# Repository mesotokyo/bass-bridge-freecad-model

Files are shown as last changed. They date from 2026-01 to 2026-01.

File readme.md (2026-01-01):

# 5弦ベース用ブリッジ3Dモデル

5弦ベース用のブリッジを作成するための3Dモデルです。この3Dモデルは板金加工での加工を意図して制作しています。

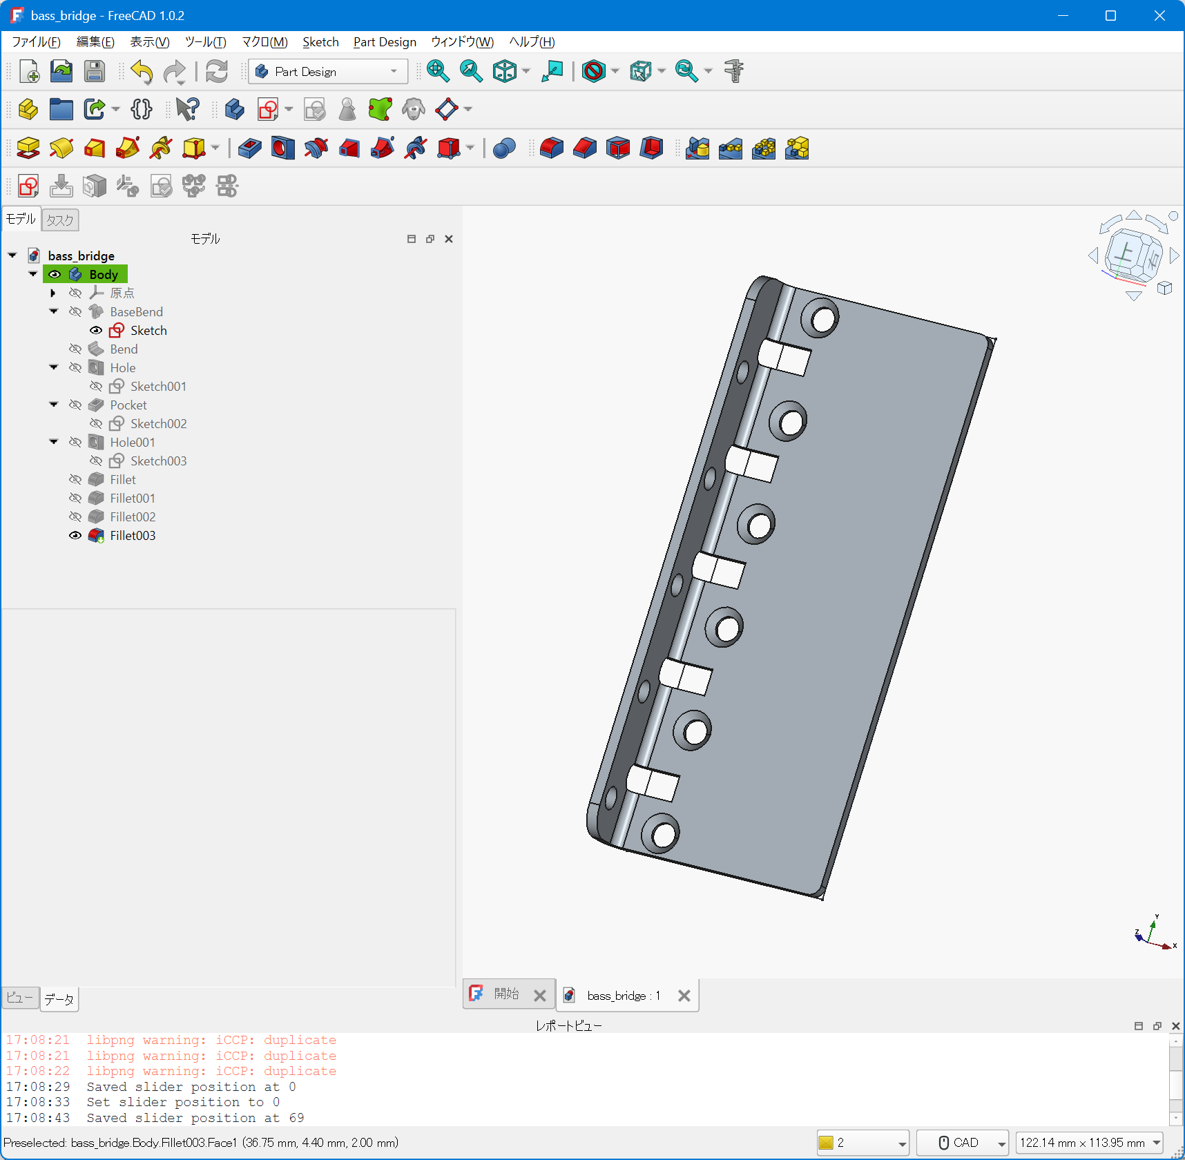
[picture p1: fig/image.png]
FreeCADで表示した全体イメージ


## 作業工程解説

FreeCADで本3Dモデルを作成する手順を[how_to_model_the_bridge](how_to_model/how_to_model_the_bridge.md)としてまとめています。ブリッジの寸法や穴の位置を変更したい場合、こちらが参考になるかもしれません。

## 寸法について

ブリッジを固定するためのネジ穴は「BADASS V」と同じ位置に配置しています。そのため、BADASS Vやその互換品（ALLPARTSの5弦ベース用「OMEGA BASS」、HIP SHOTの5STRING KICKASS BASS BRIDGEの「Mount Pattern 1」バージョン）から追加加工なしで置き換えが可能です。

ベースプレート部分の幅が41.7mm（ベース部分38mm＋曲げ部分3.7mm）、高さが100mmです。ネジ穴の間隔は18.4mmです。

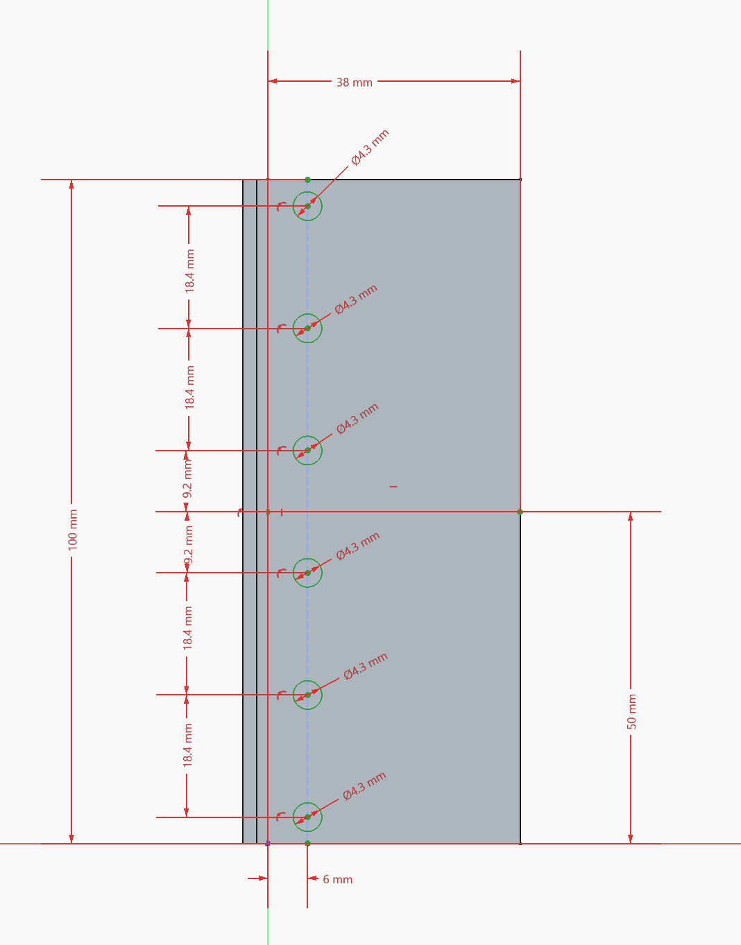
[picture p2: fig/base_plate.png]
ベースプレート部分の寸法図


弦間ピッチは19mmを想定しています。

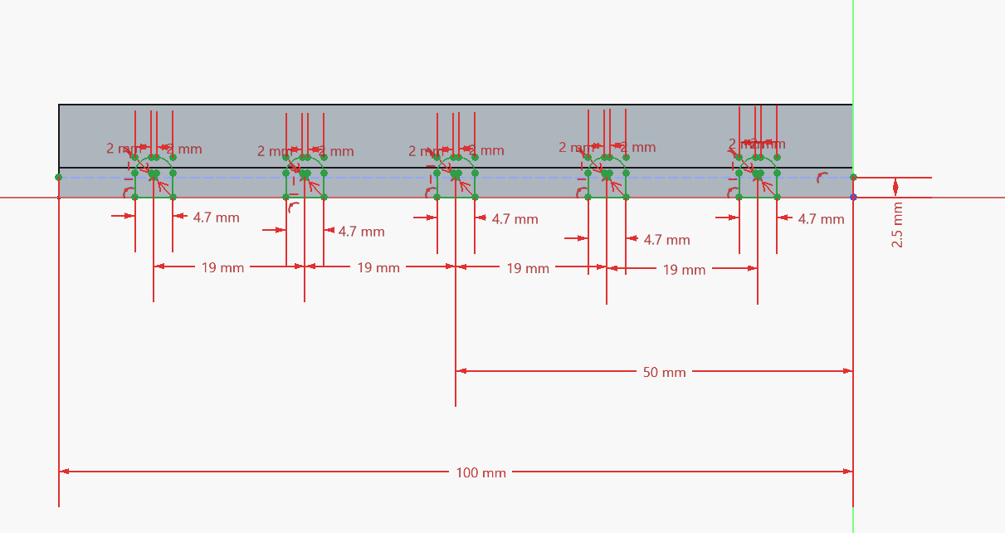
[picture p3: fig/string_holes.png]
弦を通す部分の寸法図


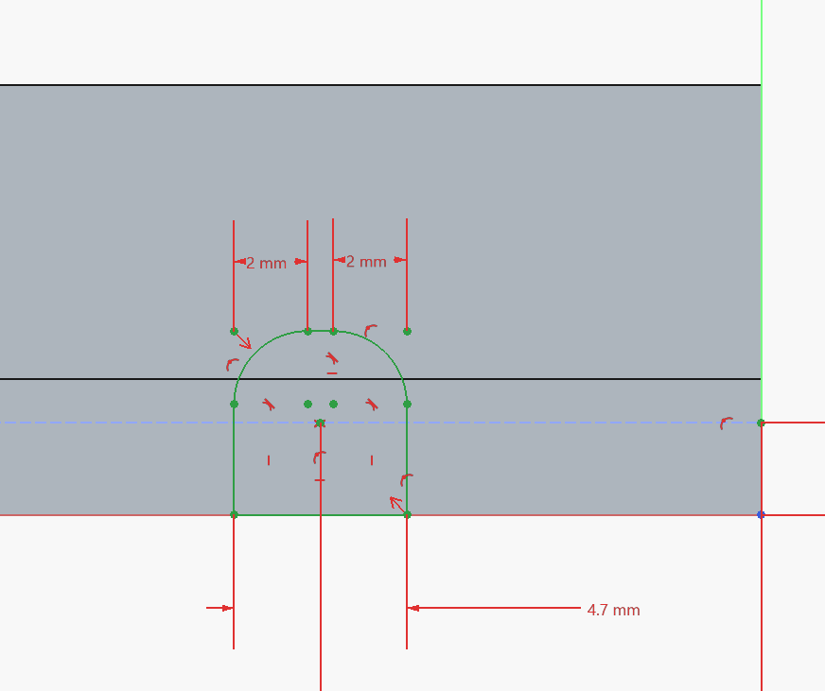
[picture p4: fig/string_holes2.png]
弦を通す穴の寸法図


サドルは19mmサイズのものを利用することを想定しています。

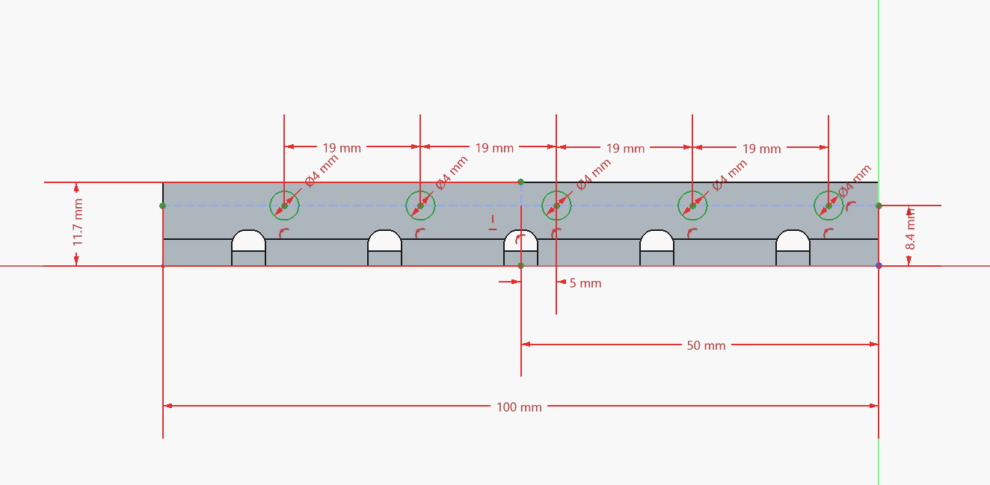
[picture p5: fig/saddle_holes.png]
サドル固定用ネジ穴の寸法図


## ライセンス

[CC-BY 4.0](https://creativecommons.org/licenses/by/4.0/deed.ja)で提供しています。

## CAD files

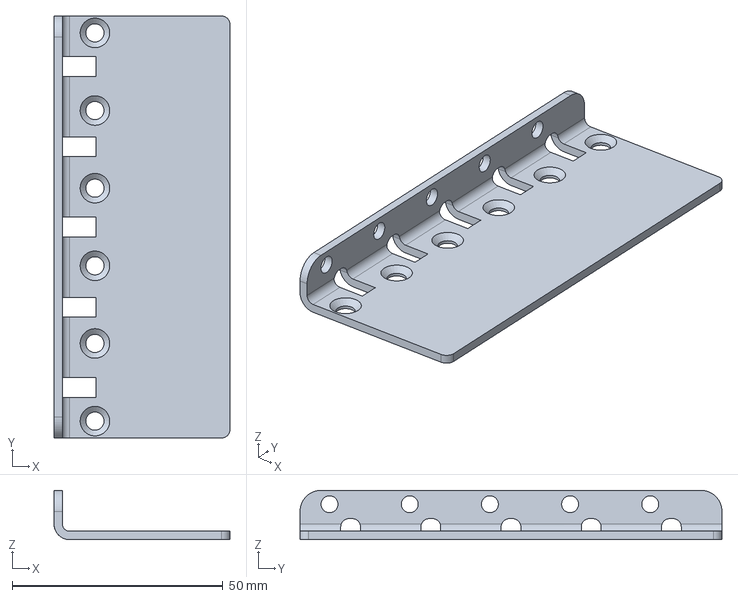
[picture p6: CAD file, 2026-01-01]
bass_bridge.FCStd
41.7 x 100.0 x 11.7 mm

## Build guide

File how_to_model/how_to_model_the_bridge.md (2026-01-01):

# FreeCADでベースブリッジを設計する

本記事では、FreeCADとSheet Metalワークベンチを使用して、板金での加工を意図した5弦ベース用ブリッジの3Dモデルを作成する方法を解説します。なお、FreeCAD自体やそのインストール方法についての解説については割愛していますので、これらについては[FreeCADのWebサイト](https://www.freecad.org/)などをご参照ください。

本記事ではFreeCAD 1.0.2のWindows版を使用しています。バージョンやOSによって画面や手順が変わる可能性がありますので、その点についてはご注意ください。

## Sheet Metalワークベンチの追加

FreeCADでは目的の操作に応じて「ワークベンチ（WorkBench）」を切り替えて作業を進めていきます。たとえば、3Dモデルに対してさまざまな操作を行うには「Part Design」ワークベンチを使います。ワークベンチの切り替えは、ツールバーのドロップダウンメニューで行えます。

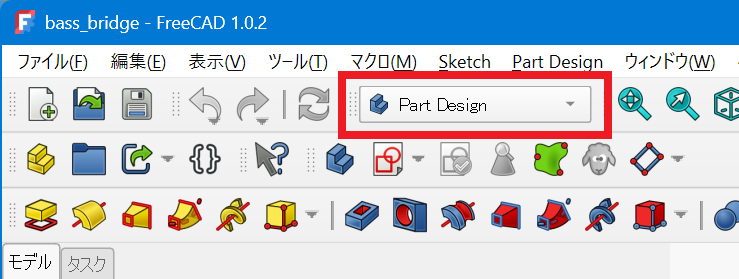
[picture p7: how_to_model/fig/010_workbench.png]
ワークベンチを選択するドロップダウンメニュー


板金加工に関連する操作は「Sheet Metal」ワークベンチで行います。このワークベンチはFreeCADには標準では含まれていないため、別途アドオン（拡張機能）の追加を行う必要があります。アドオンの追加はFreeCADを起動して「ツール」－「拡張機能の管理」メニューで行えます。

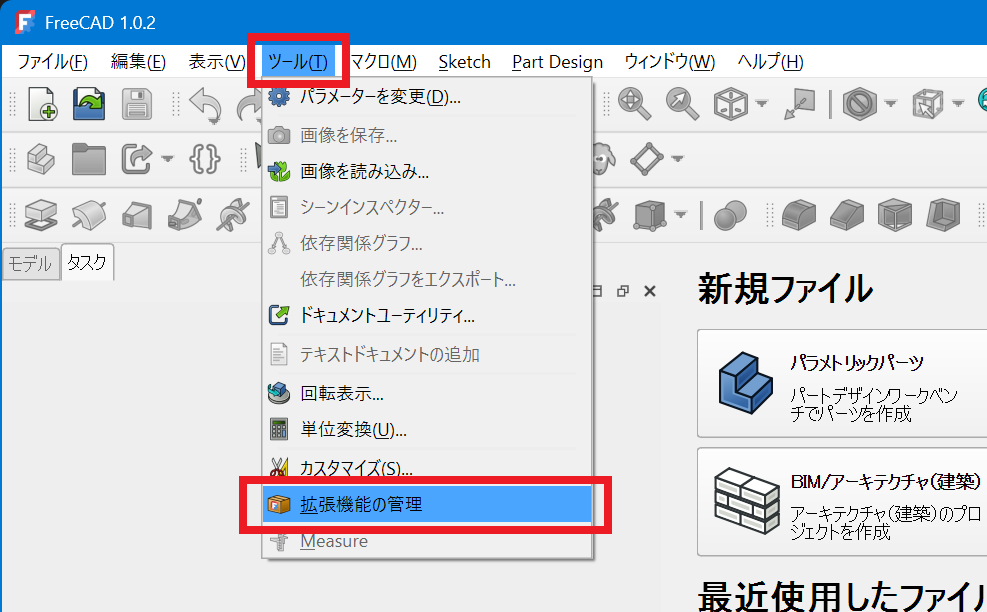
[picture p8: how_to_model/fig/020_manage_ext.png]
「拡張機能の管理」メニューでアドオンを追加できる


このメニューを選択すると、「アドオン・マネージャー」が表示されるので、ここで「SheetMetal Workbench」をクリックしてインストールを行います。画面右上に表示するアドオンを絞り込む検索ボックスがあるので、ここに「sheet」などのキーワードを入力すると探しやすいでしょう。

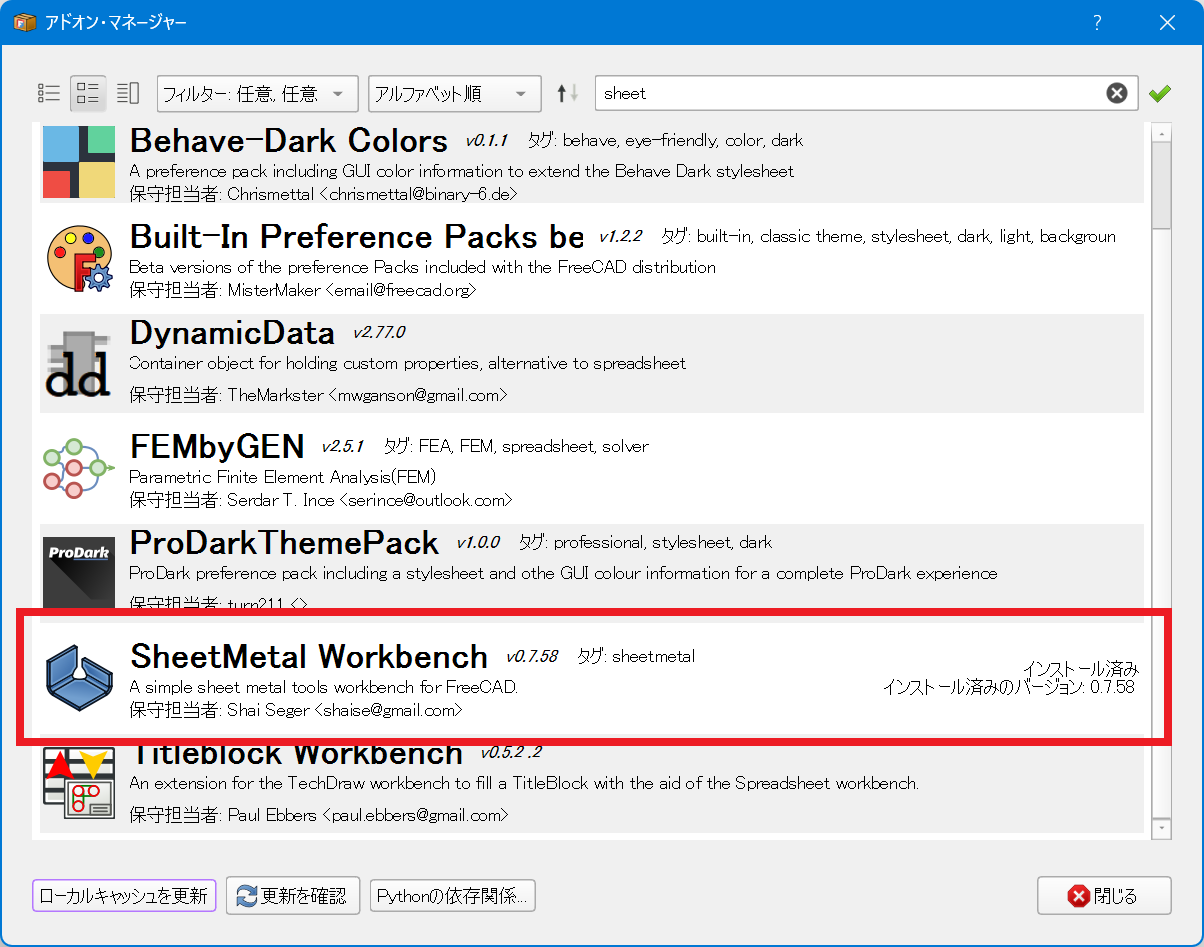
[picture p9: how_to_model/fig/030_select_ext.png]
「アドオン・マネージャー」で「SheetMetal Workbench」をインストールする


## FreeCADの操作について

FreeCADはAdobe Illustratorなどのベクターグラフィックス作成ツールに似ていますが、操作方法などはかなり異なります。たとえば、画面のスクロールはマウス中ボタン（ホイール）のドラッグで行います。始点変更は中ボタン＋右ボタン同時押し（厳密には中ボタンを押したあと、押しっぱなしにしたまま右ボタンを押す）のドラッグ操作で、表示の拡大・縮小はホイール操作で行えます。

また、図形作成などの作業中にマウスの右ボタンを押すと、その作業をキャンセルできます。Escキーでも作業をキャンセルできますが、Escキーにはタスクを閉じてワークベンチを切り替える操作も割り当てられており、Escキーを連打すると意図せずワークベンチが切り替わってしまうことがあるため、作業のキャンセルにはなるべく右クリックを使うことをおすすめします。

## ファイルの新規作成とボディーの作成

それでは、実際にモデリングを進めていきます。まず、ファイルの新規作成を行います。FreeCADを起動すると「開始」というタブが表示されるので、そこで「新規ファイル」以下にある「空ファイル」をクリックします（ツールバーの「新規」ボタンでも同じ操作が可能です）。

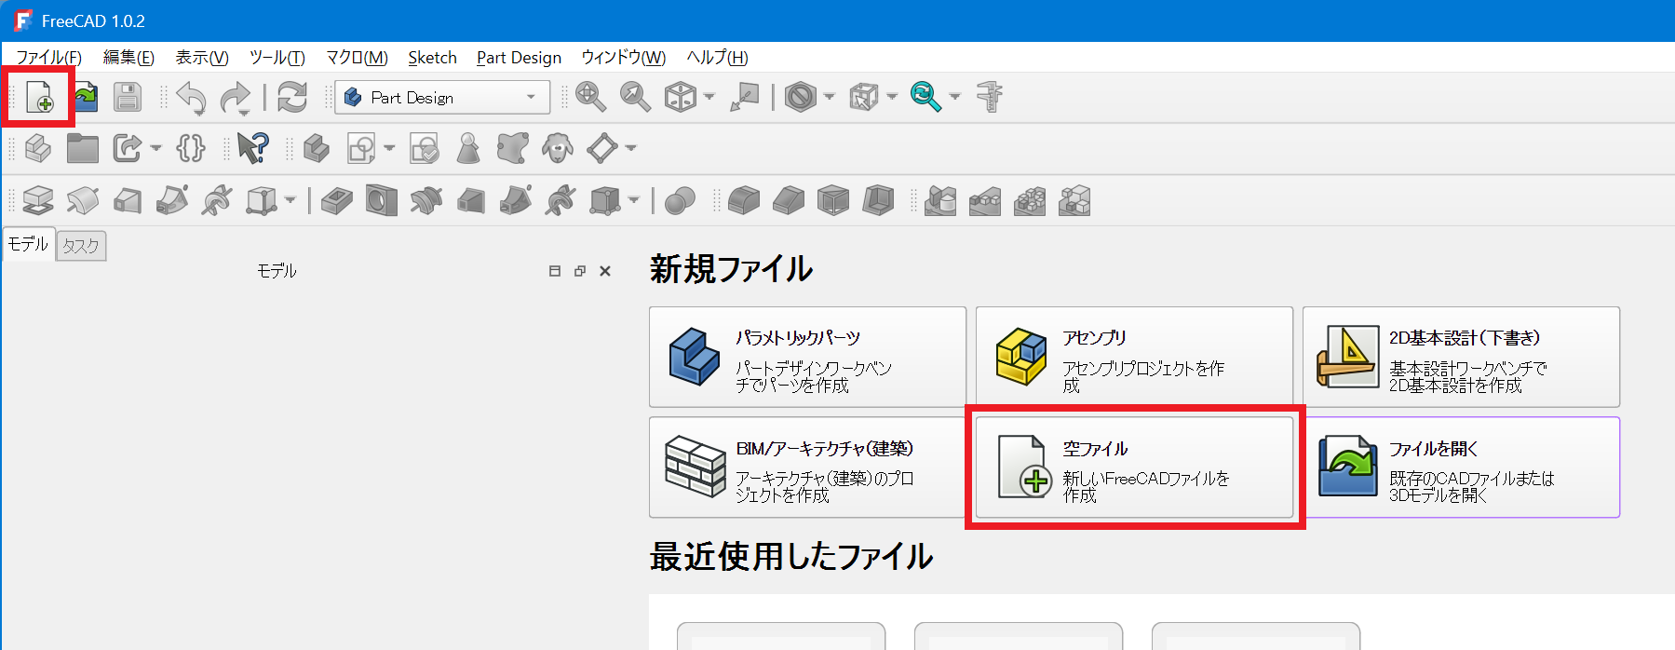
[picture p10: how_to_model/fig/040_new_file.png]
「開始」タブの「空ファイル」、もしくはツールバーの「新規」ボタンでファイルを新規作成できる


すると、「名称未設定」というタブが追加され、また「モデル」タブに「名称未設定」というアイテムが追加されます。作業を進める前に、ひとまず「ファイル」－「名前を付けて保存」メニューを選択し、適当な名前でファイルを保存しておきましょう。今回は「bass_bridge」というファイル名で保存していますが、もちろんそれ以外のファイル名でも構いません。ここで保存を行うと、「名称未設定」と表示されていた部分が指定したファイル名に変わります。

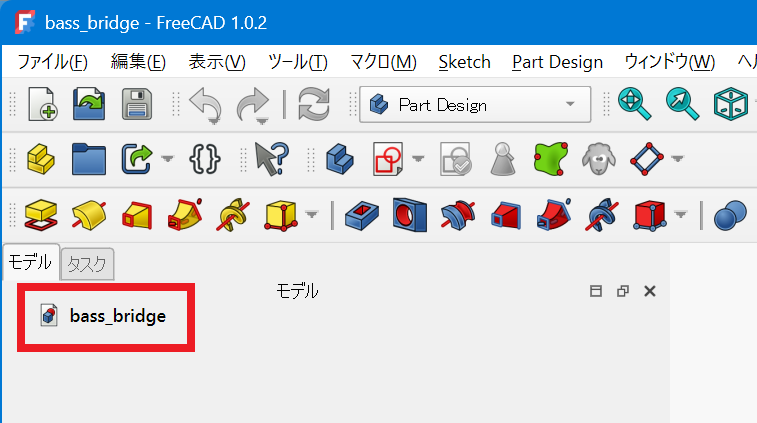
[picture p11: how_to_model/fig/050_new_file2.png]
ファイルを保存すると「モデル」タブ内の表示がそのファイル名に変わる


さて、FreeCADで3Dモデルを作成するには、最初に「ボディー（Body）」を作成する必要があります。「ボディー」という表記だと分かりにくいかもしれませんが、これは作業対象の「本体」のことを指しています。

ボディーを作成するには、モデルタブで作成対象のファイル（今回は「bass_bridge」）を選択した状態で「タスク」タブの「ボディーを作成」をクリックします。

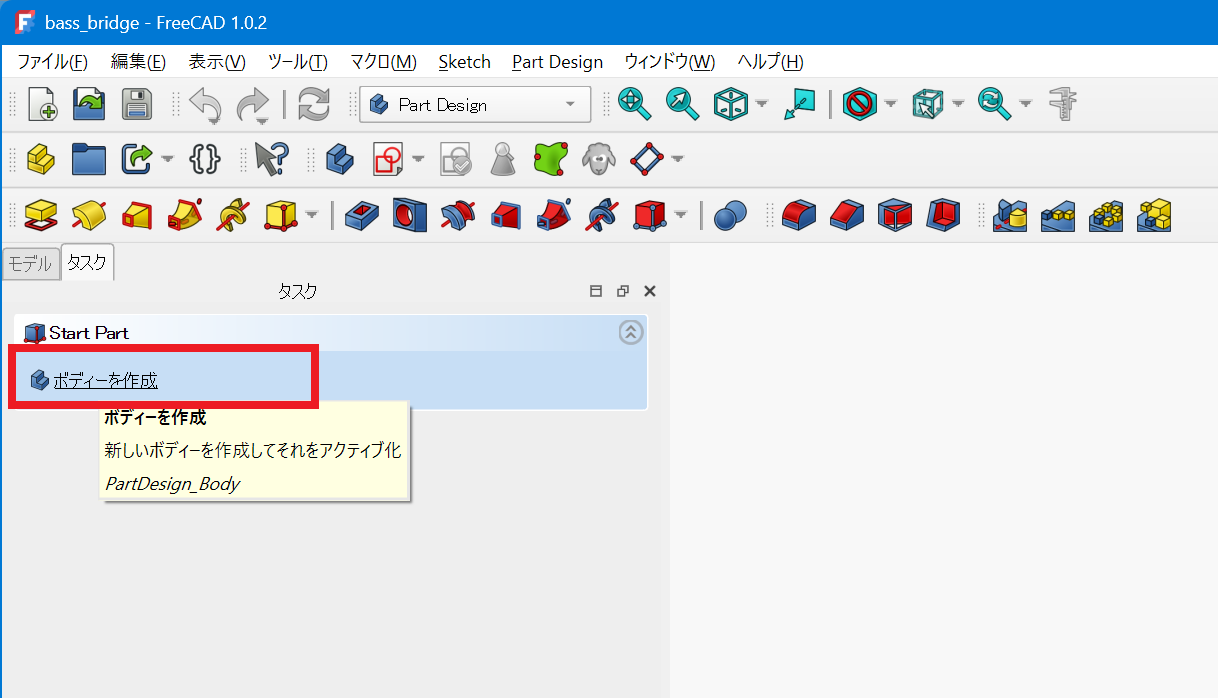
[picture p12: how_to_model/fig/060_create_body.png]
「タスク」タブの「ボディーを作成」をクリックすることでボディーを作成できる


すると、「モデル」タブ内の「bass_bridge」（ここには作成しているファイル名が入ります）の下に「Body」という項目が作成されます。

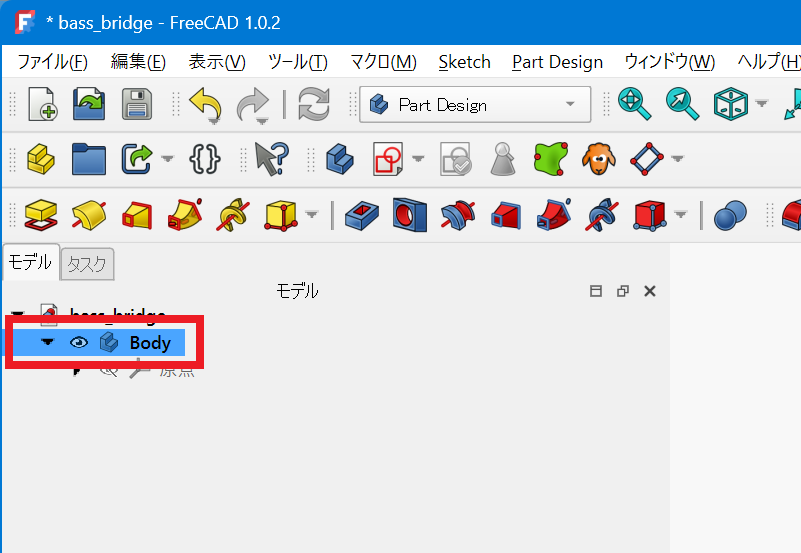
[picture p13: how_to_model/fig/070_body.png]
モデルタブ内に「Body」という項目が作成される


FreeCADではこのBodyの中に「スケッチ（Sketch）」と呼ばれる2次元（平面）の下書きを作成し、それを3D化することでモデリングを進めていきます。

## 台座部分を作成する

それでは、まずはブリッジの台座部分（エレキベース本体と接する部分）を作成していきましょう。まずはBodyにスケッチを追加します。スケッチは、モデルタブでBodyを選択した状態で「タスク」タブを開き、「スケッチを作成」をクリックすることで作成できます。

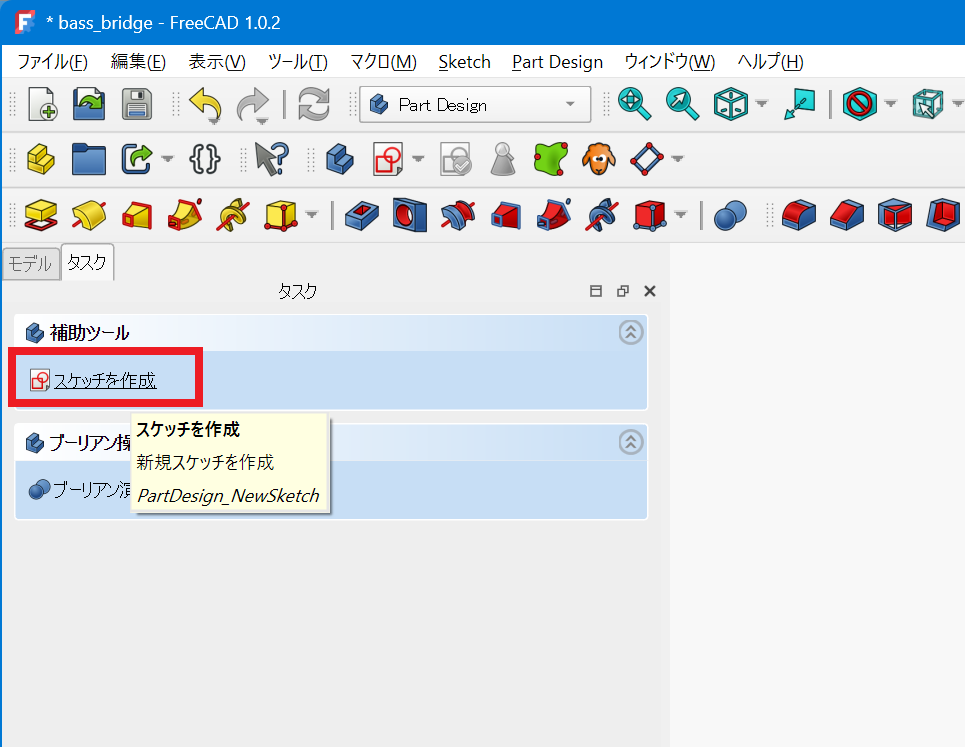
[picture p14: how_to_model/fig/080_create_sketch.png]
Bodyを選択した状態で「スケッチを作成」をクリックする


すると「アタッチメントを選択」という画面が表示されます。ここでは、作成したスケッチをどの平面上に貼り付けるか（アタッチするか）を選択します。まだボディー上には何も存在しない状態なので、ここでは「XY平面」を選択して「OK」をクリックします。

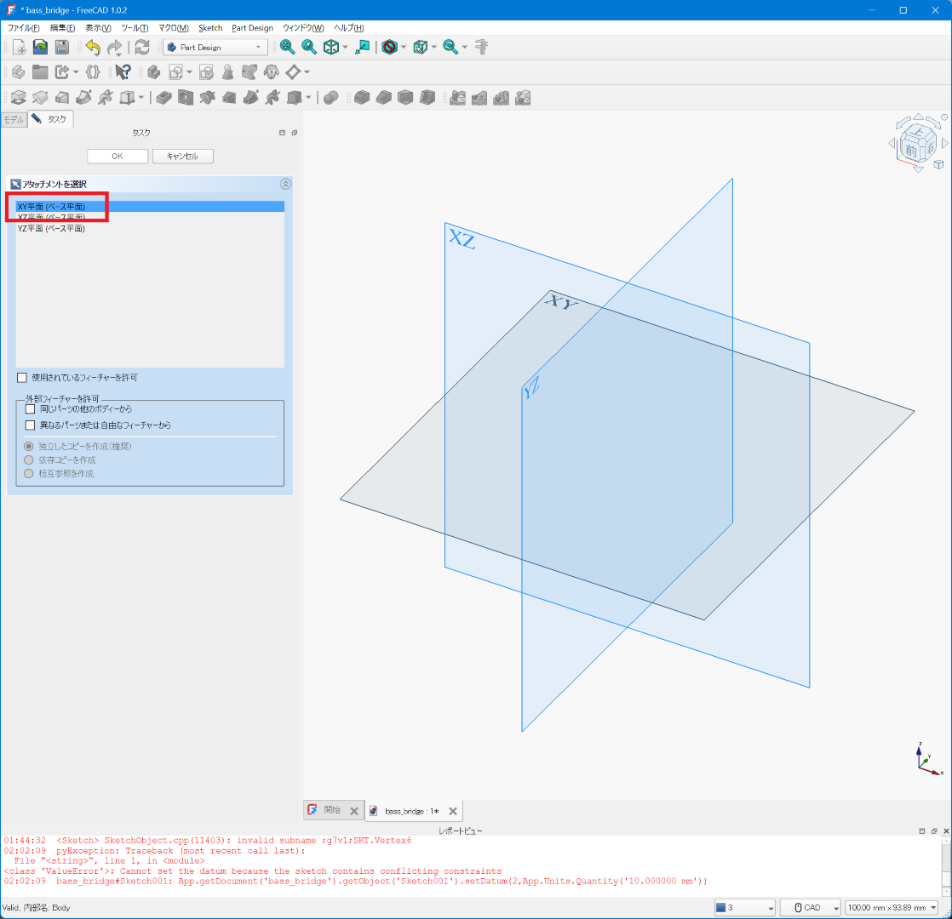
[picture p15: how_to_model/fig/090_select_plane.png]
スケッチを「XY平面」上にアタッチする


これによってXY平面上にスケッチが作成され、「Sketcher」ワークベンチに切り替わってその平面上でスケッチの編集が行えるようになります。

なお「Sketcher」などのワークベンチでは、何もタスクを実行していない状態で「Esc」キーを押すと「Part Design」ワークベンチに戻ってしまいます。この場合、「モデル」タブで「Sketch」などの編集したい項目をダブルクリックすることで、その項目を編集するワークベンチに戻ることができます。

続いて台座となる長方形をスケッチ上に描いていきます。まずはSketchを開いた状態でツールバーの「構築ジオメトリの切り替え」ボタンが白い実線を強調する表示になっていることを確認します。もし青い点線を強調する表示になっている場合は、このボタンをクリックすると白い実線に切り替わるはずです。

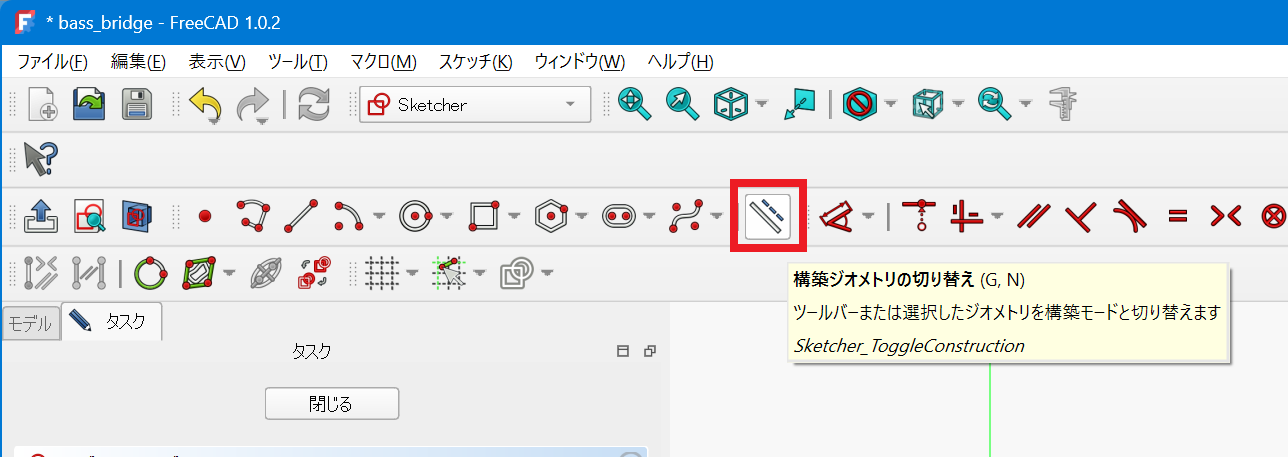
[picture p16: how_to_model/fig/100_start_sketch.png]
「構築ジオメトリの切り替え」ボタンで白い実線が強調されていることを確認する


長方形を描くには、この状態でツールバーの「長方形を作成」ボタンをクリックします。

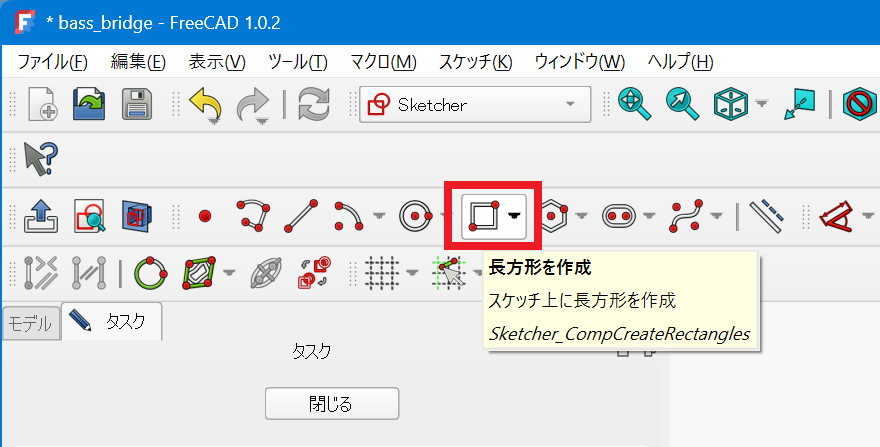
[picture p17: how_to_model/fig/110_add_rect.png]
「長方形を作成」ボタンをクリックする


次に、座標軸の原点近くにマウスカーソルを動かします。すると、マウスカーソルの横に「×」のようなアイコンが表示されるので、ここでマウスの左ボタンをクリックします。

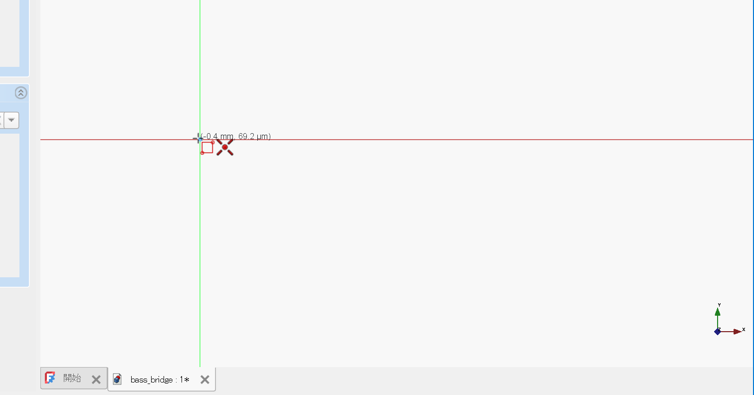
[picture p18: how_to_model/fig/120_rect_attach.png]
「座標軸の原点近くにマウスカーソルを動かすと、カーソルの横に「×」のようなアイコンが表示される


この「×」アイコンは、描画する点がその位置に拘束される（その位置に固定される）ということを意味しています。今回の例では、これから描こうとする長方形の頂点の1つが原点に固定されることになります。この状態でマウスを動かすことで、作成する長方形の縦横のサイズを変更できます。この状態で適当なサイズになるようマウスを動かして左ボタンをクリックすると長方形が作成されます。なお、この段階では厳密に目的のサイズの四角形を描く必要はありません。

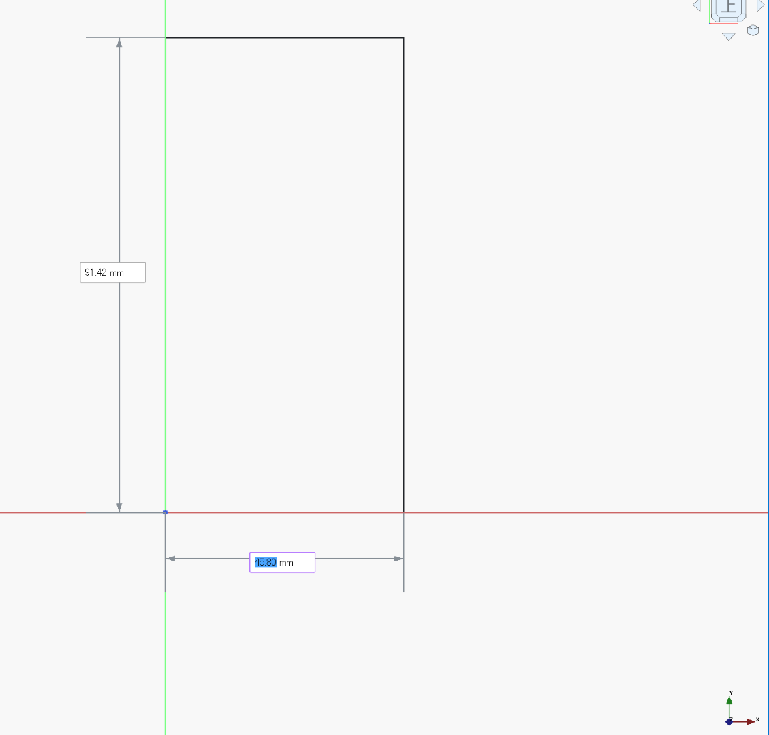
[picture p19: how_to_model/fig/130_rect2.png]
マウスを動かしてクリックし、適当なサイズの長方形を作成する


次に、この長方形の幅と高さを寸法として記入します。たとえば高さを100mmに設定する場合、まずマウスの右ボタンをクリックして何も選択されていない状態にしたうえで長方形の縦の辺をクリックして選択し、続いてツールバーの「寸法」ボタンをクリックします。

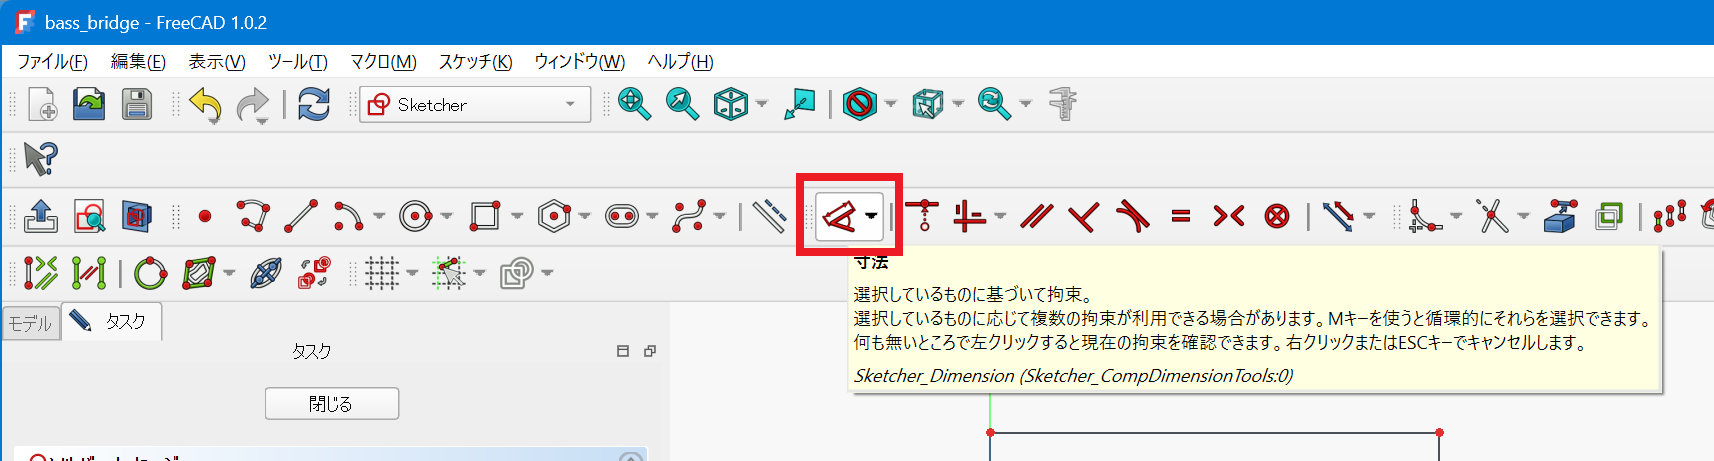
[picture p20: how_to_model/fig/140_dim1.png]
寸法を設定したい辺をクリックしてから「寸法」ボタンをクリックする


寸法線が表示されるので、マウスで寸法の表示位置を動かし、右クリックで表示位置を確定させます。

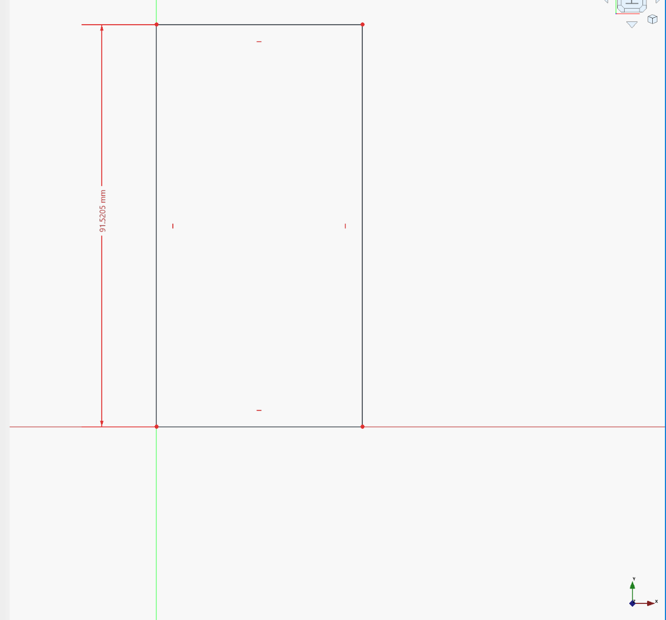
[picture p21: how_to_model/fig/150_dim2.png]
マウスで寸法を記入する場所を指定する


すると「長さを挿入」ダイアログが表示されるので、ここで高さ（今回は100mm）を入力して「OK」をクリックします。

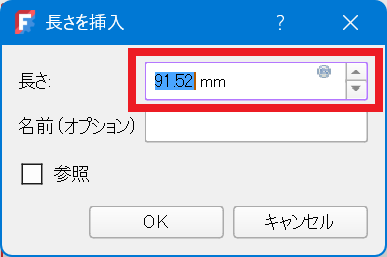
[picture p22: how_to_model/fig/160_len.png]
「長さを挿入」ダイアログで長さを入力する


すると、ここで入力した寸法に合せて自動的に長方形のサイズが変更されます。同様に長方形の横の辺をクリックして、幅の寸法（今回は38mm）も設定します。

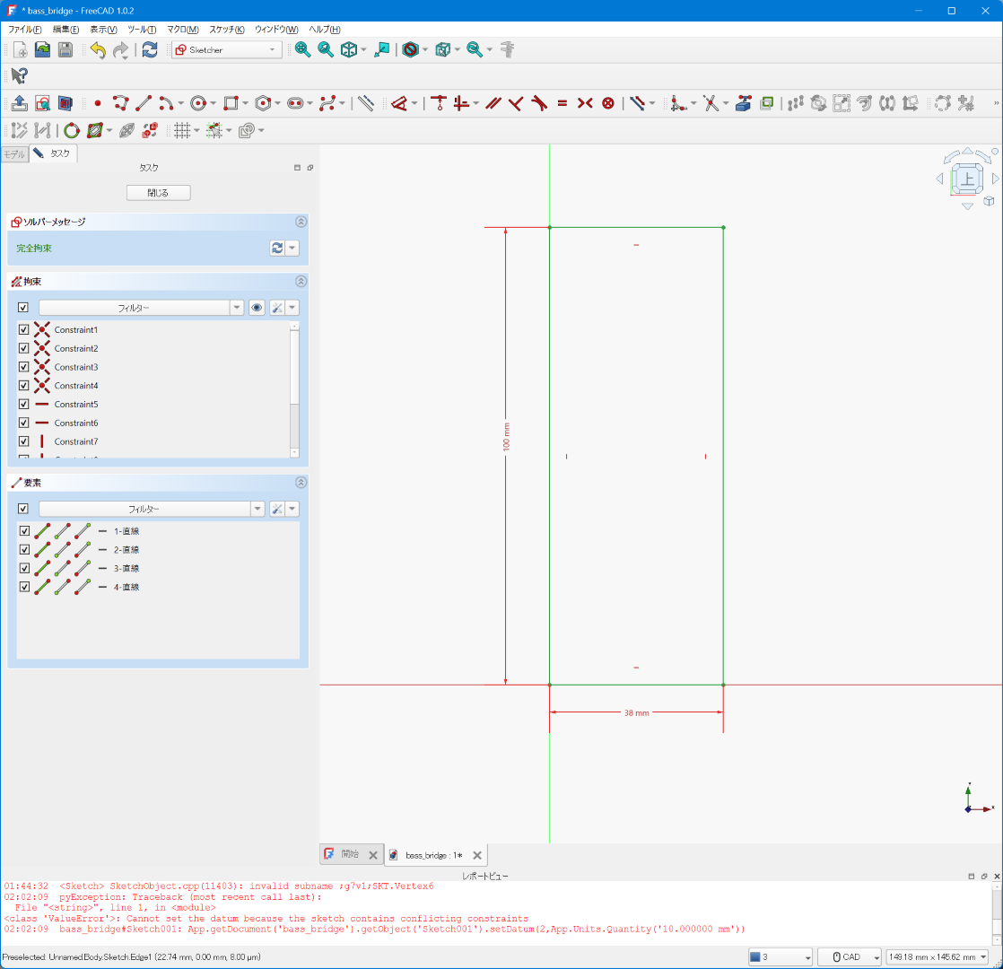
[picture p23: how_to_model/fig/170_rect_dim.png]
寸法を入力するとその値に応じて自動的に図形のサイズが変わる


ちなみに、ここで指定する寸法はあくまで台座部分の幅と高さです。板金加工ではまず板を所定の寸法にカットしてから曲げ加工を行いますが、この段階では曲げ加工のことは考えずに、単純に台座部分の幅と高さのみを指定すればOKです。

さて、今回は最初に四角形を描く際に頂点の1つを原点に固定し、かつそこから縦と横の長さを寸法線によって設定しました。これによって、長方形の位置とサイズがこの図面上で完全に確定します。このように位置とサイズが完全に確定した状態を「完全拘束」と呼びます。完全拘束状態になった図形は緑色の実線で表示され、またスケッチ上のすべての図形が完全拘束状態に鳴っている場合、タスクタブの「ソルバーメッセージ」に「完全拘束」と表示されます。図形が完全拘束状態になっていない場合、続く立体化操作の際にエラーが表示されることがあります。その場合、寸法線の記入漏れなどがないかを確認し、必要に応じて寸法線などを追加して図形が完全拘束状態になるようにします。

続いて、このスケッチに記入した図形を立体化して台座を作成します。まずタスクタブの「閉じる」ボタンをクリックし、Part Designワークベンチに戻ります。続いて「Sheet Metal」ワークベンチに切り替えてからBody以下のSketchを選択します。ツールバーの「Make Base Wall」ボタンが有効になるので、このボタンをクリックします。

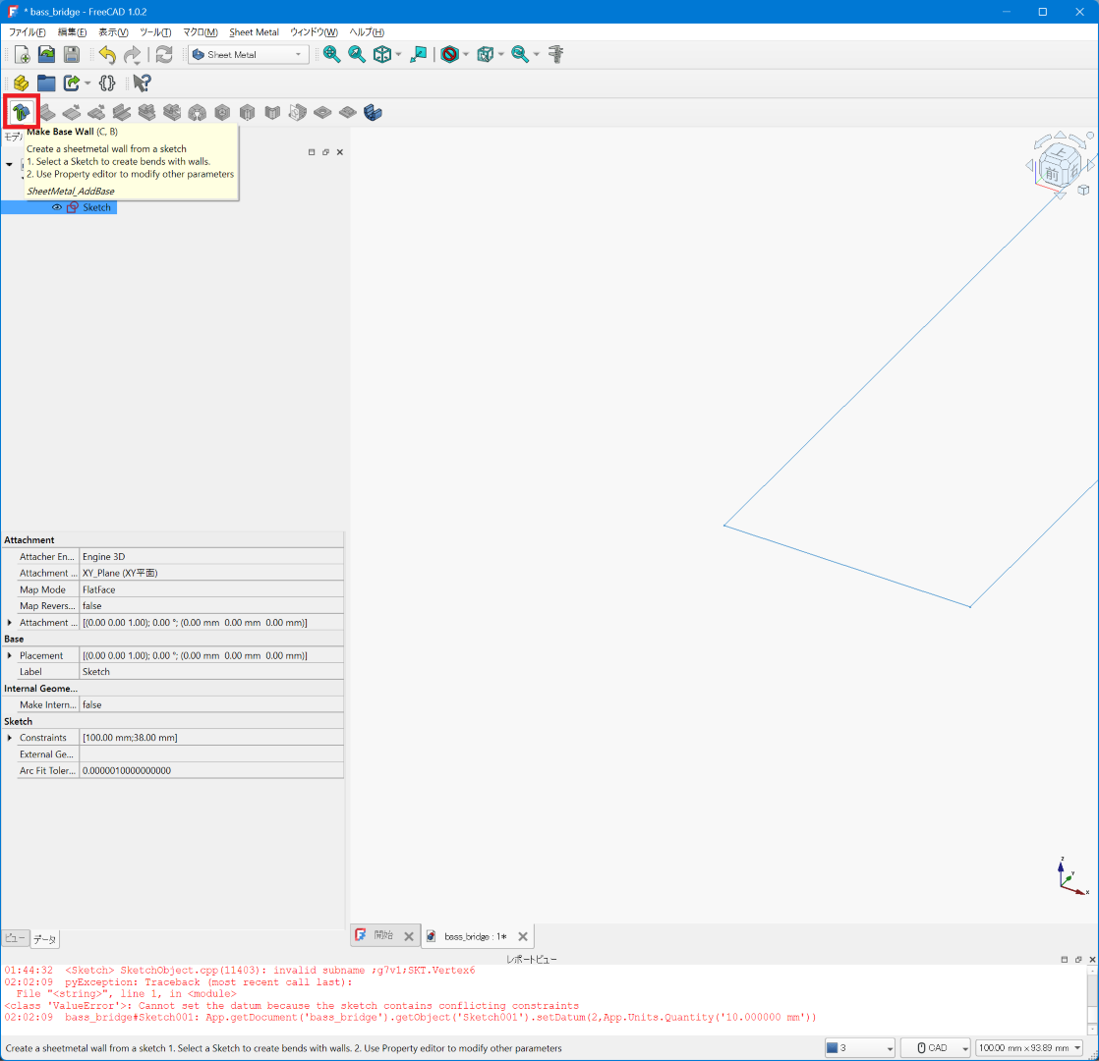
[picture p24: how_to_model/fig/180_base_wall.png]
「Sheet Metal」ワークベンチに切り替えてスケッチを選択し、「Make Base Wall」ボタンをクリックする


するとタスクタブに「Sketched base shape properties」という設定項目が表示されるので、「Thickness」欄に板の厚み（今回は2mm）を入力して「OK」をクリックします。

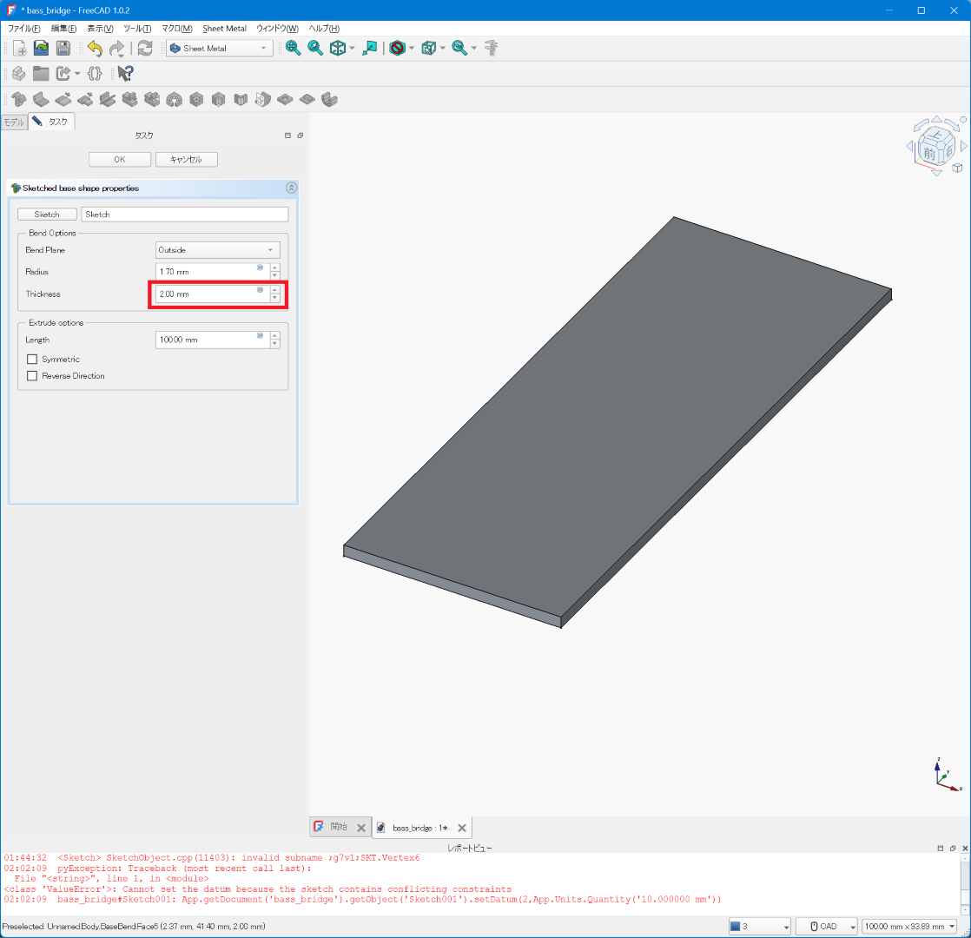
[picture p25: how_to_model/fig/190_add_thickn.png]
「Sketched base shape properties」の「thickness」で板の厚みを指定する


すると台座部分となる板の3Dモデルが作成され、またモデルタブのBodyの下にこれに対応する項目が「BaseBend」という名前で作成されます。このとき、最初に作成していたスケッチはこのBaseBend項目の下に残っており、これをダブルクリックして再編集することで、台座のサイズをあとから修正できます。

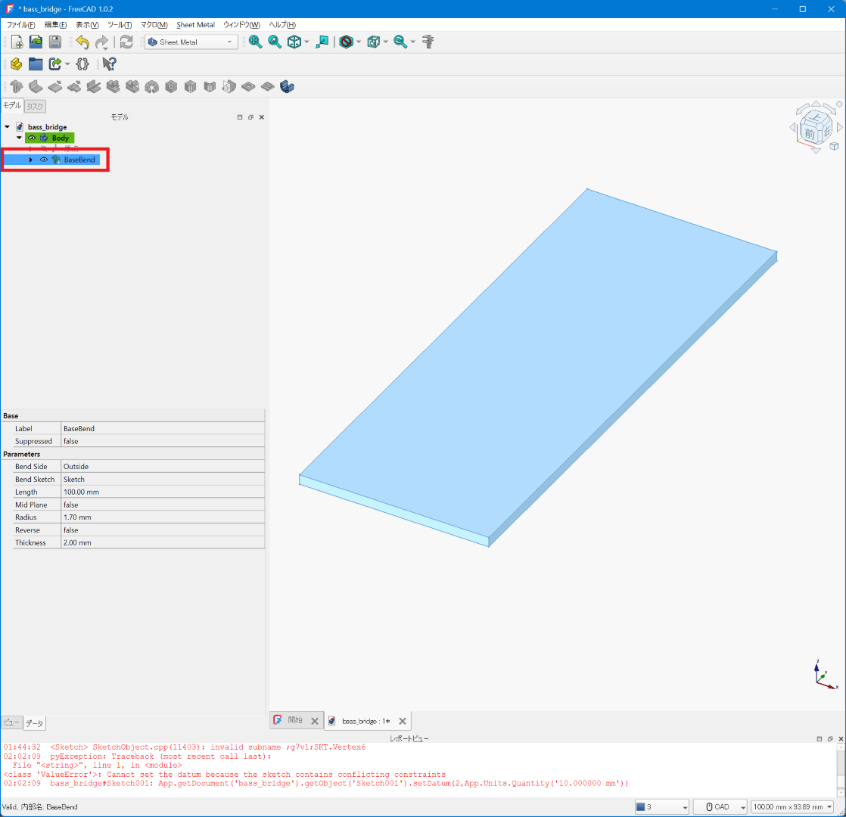
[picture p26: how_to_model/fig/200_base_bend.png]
「BaseBend」として台座部分が作成される


## 折り曲げた部分（弦を通す部分）の作成

続いて、台座部分から板を垂直に曲げた部分（弦を通す部分）を作成します。まず、Sheet Metalワークベンチに切り替わっている状態でモデルタブで「BaseBend」を選択します。もしタスクタブにタスクが表示されている場合は「キャンセル」をクリックしてタスクが選択されていない状態にします。この状態で台座部分の左上の辺をクリックして選択し、続けて「Make Wall」ボタンをクリックします。

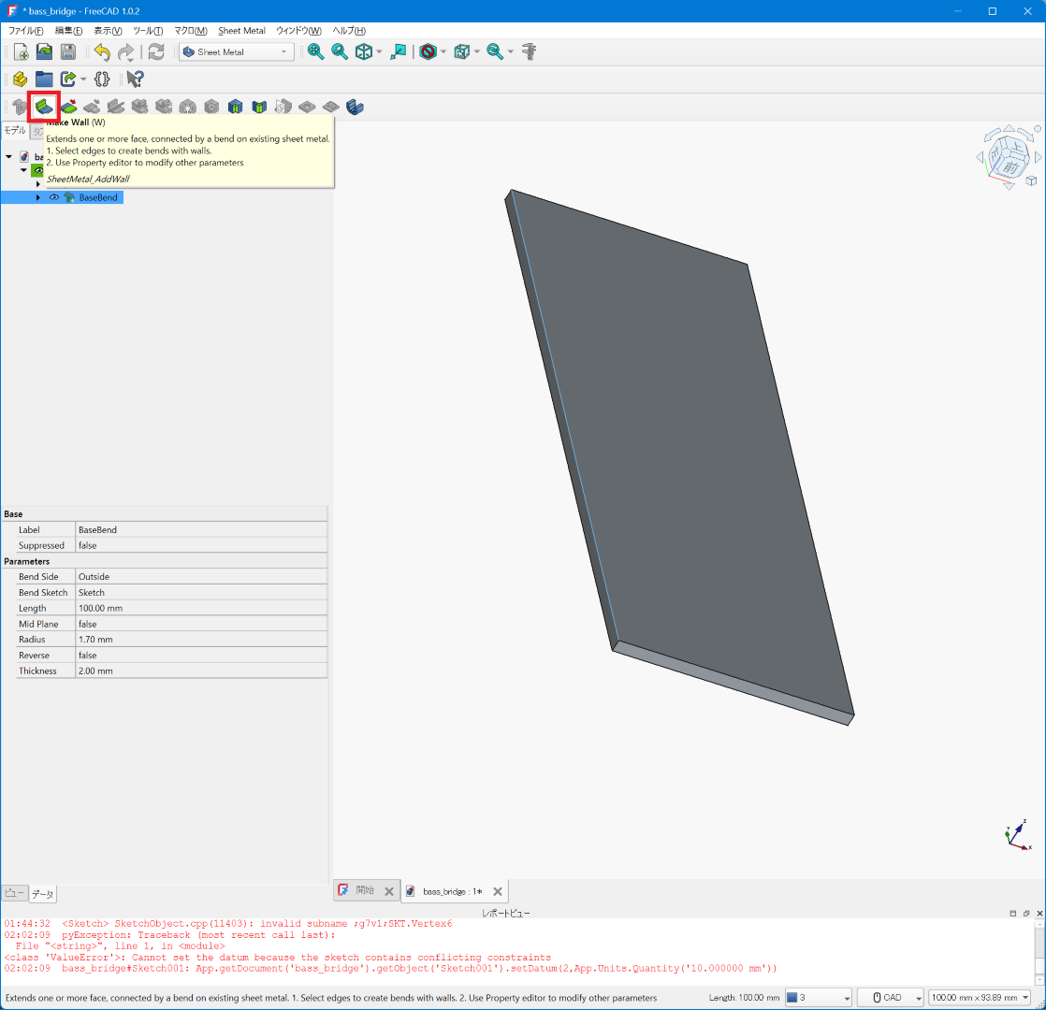
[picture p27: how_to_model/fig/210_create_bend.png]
折り曲げた部分を作成したい辺を選択して「Make Wall」ボタンをクリックする


タスクタブに「Flange properties」という設定項目が表示されるので、ここに必要な値を入力して「OK」をクリックします。ここでは曲げた部分の長さ（「Length」）、曲げ部分の直径（「Bend radius」）や曲げ角度（「Bend angle」）、曲げ方（「Wall position」）などを選択できます。今回は長さ8mm、曲げ部分の直径は1.7mm、角度90度で、Wall positionは「Material Outsite」（台座部分の外側に作成）を指定しました。

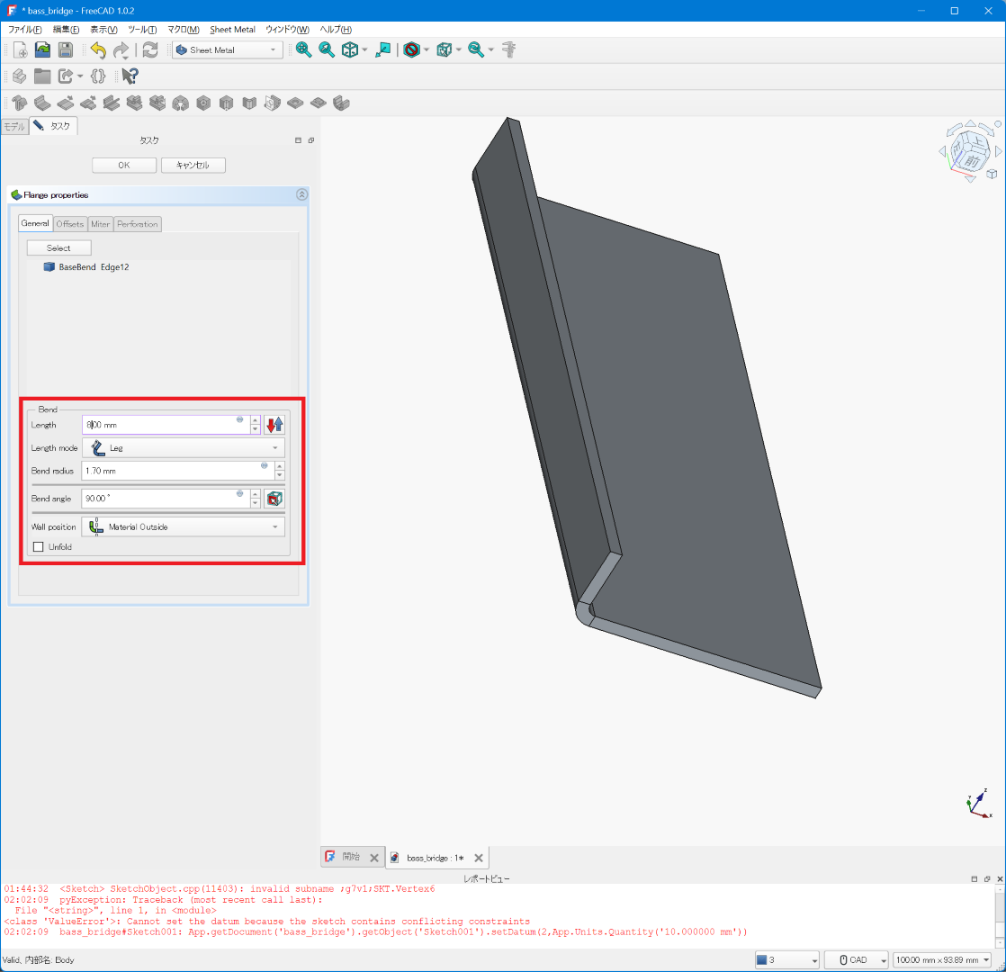
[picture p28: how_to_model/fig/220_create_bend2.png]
折り曲げた部分のサイズや曲げ角度などを「Flange properties」で入力する


すると台座の横から板を曲げるようにして垂直に立ち上がった部分が3Dモデルとして作成され、あわせてモデルタブのBody以下にこの立ち上がった部分（弦を通す部分）に対応する「Bend」という項目が作成されます。

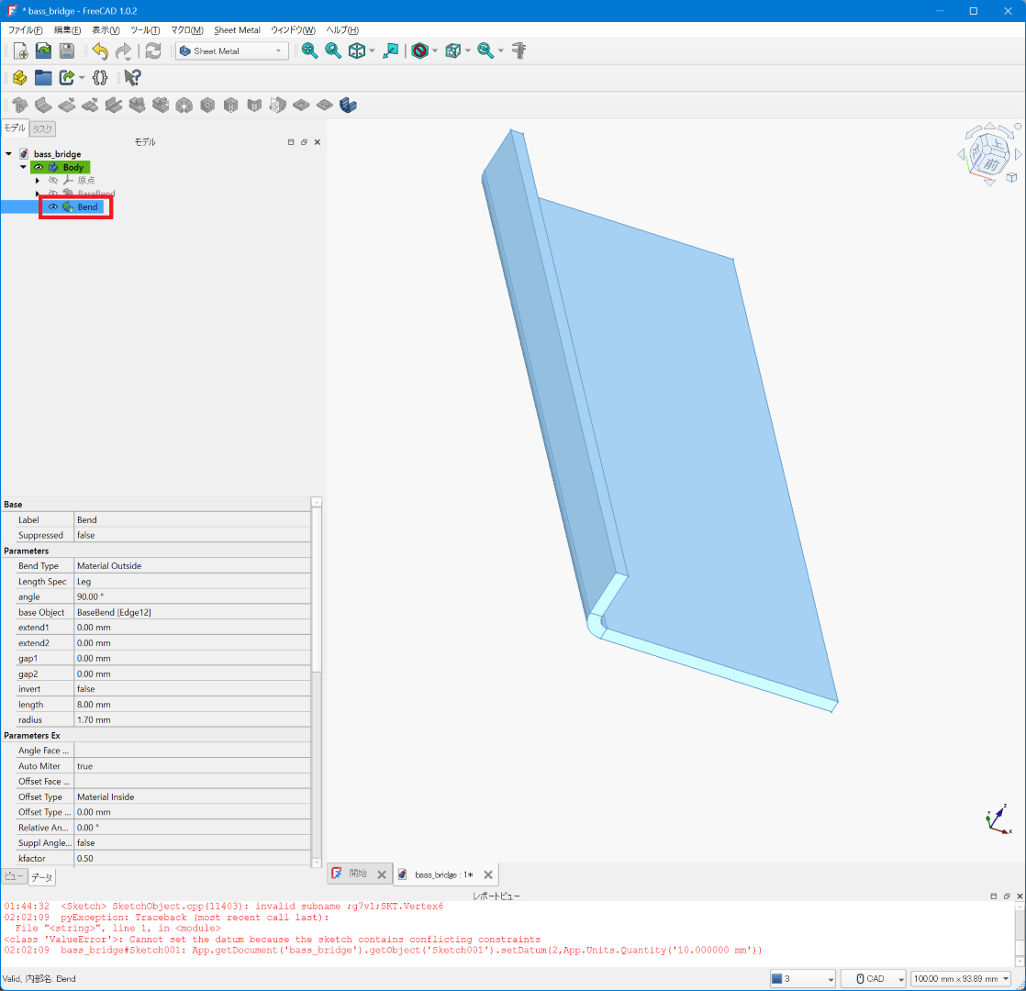
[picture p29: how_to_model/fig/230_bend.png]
折り曲げた部分は「Bend」という項目として作成される


## 台座部分のネジ穴を作成する

次は台座を固定するためのネジ穴を作成していきます。ネジ穴の寸法指定は台座の上面に接した2次元平面上で行うので、この台座の上面に張り付いたスケッチを作成し、そこで穴の位置を指定していきます。まずは「Part Design」ワークベンチに切り替えてから台座部分の上面をクリックして選択し、この状態でタスクタブの「表面ツール」内にある「スケッチを作成」をクリックします。

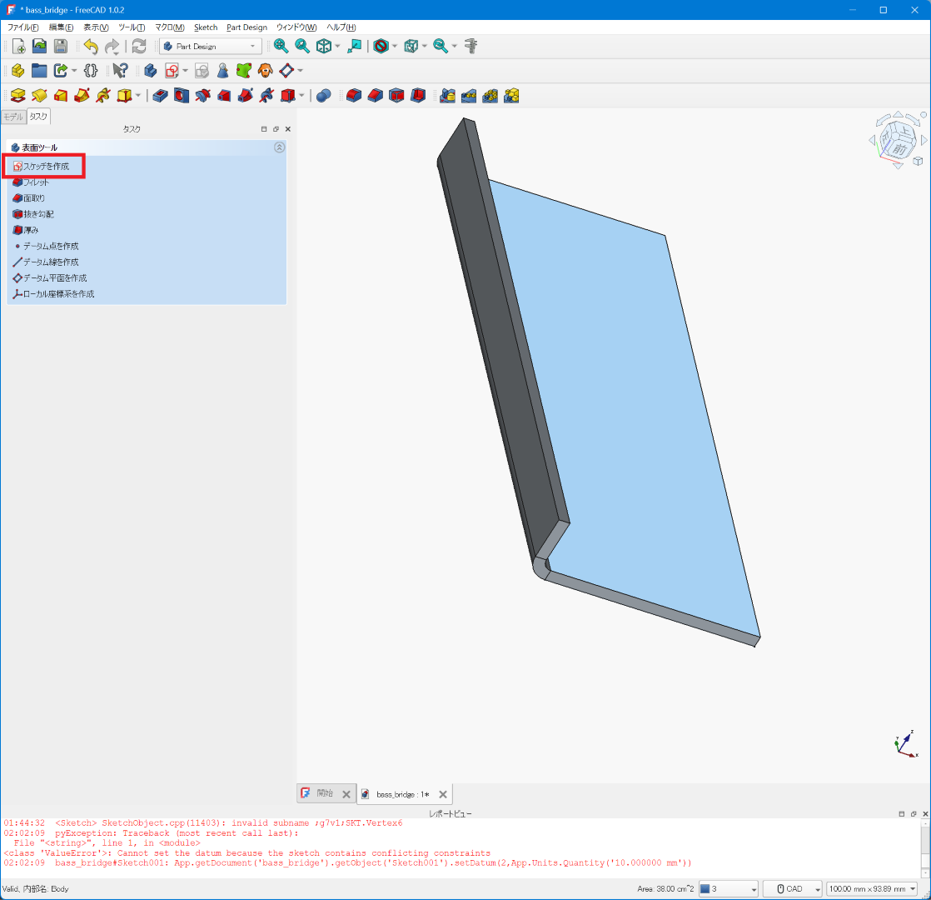
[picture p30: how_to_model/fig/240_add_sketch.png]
台座部分の上面を選択した状態で「スケッチを作成」をクリックする


すると、この平面を基準とした状態でスケッチが作成され、図形を描けるようになります。このスケッチはモデルタブ内では「Bend」の下の「Sketch001」という名前の項目に対応しています。もしほかのワークベンチに切り替えてしまった場合は、この項目をダブルクリックすることでSketchワークベンチに切り替えてこのスケッチを編集することができます。

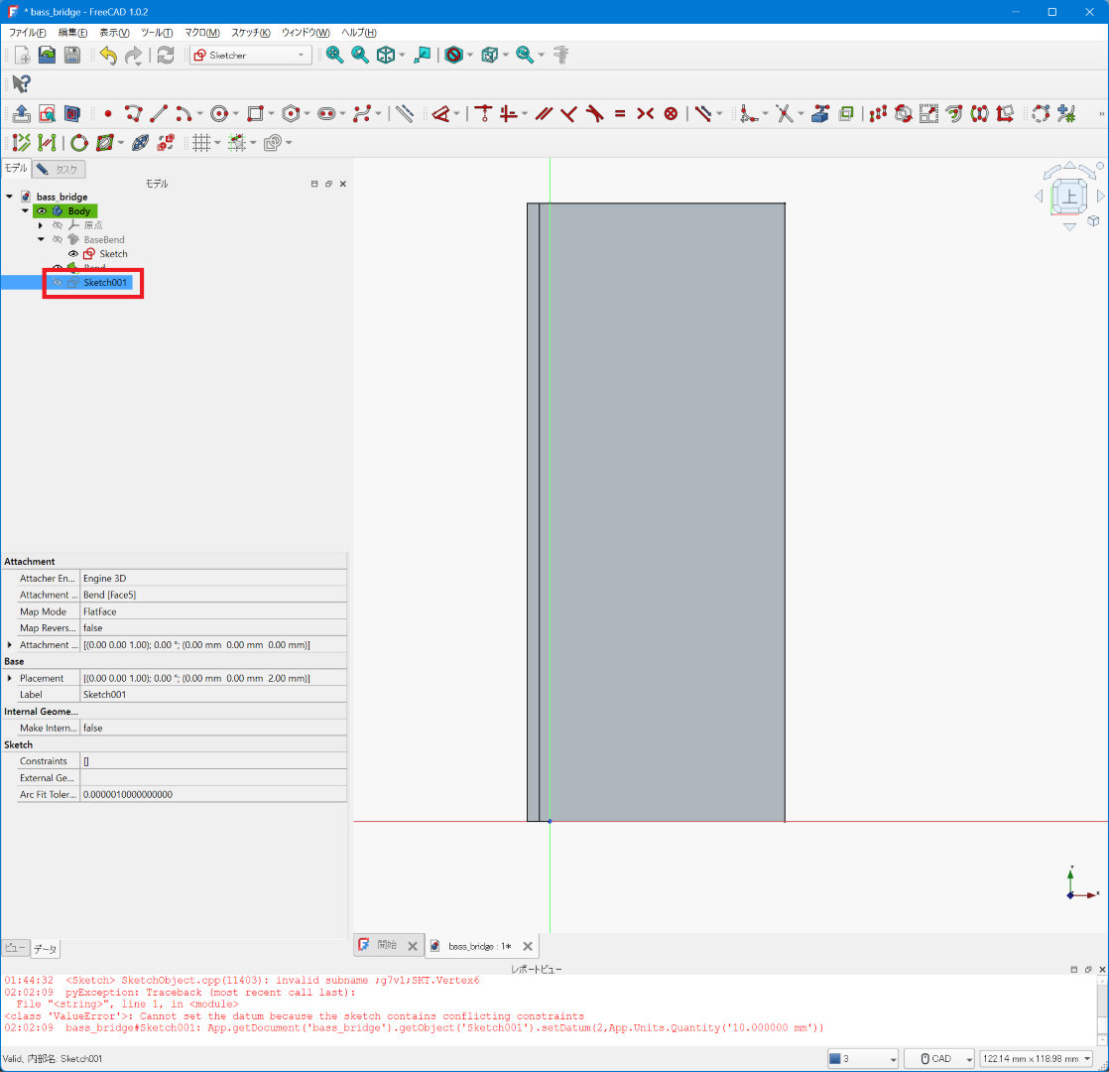
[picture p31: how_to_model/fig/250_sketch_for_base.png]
台座上面に張り付いたスケッチが作成される


さて、台座を固定するためのネジ穴は合計で6つ作成し、それぞれのネジ穴の中心は台座の左端（つまりスケッチのY軸）と平行な一直線上に並んでいます。こういった場合、補助線（construction line、構築線、構築ジオメトリ）を利用することでまとめて位置を指定できます。なお、補助線として描いた図形は3D化の際には無視されるため、自由に必要なだけ作成することが可能です。

補助線を作成するには、ツールバーの「構築ジオメトリの切り替え」ボタンをクリックします。すると、このアイコンが青い点線表示になるはずです。

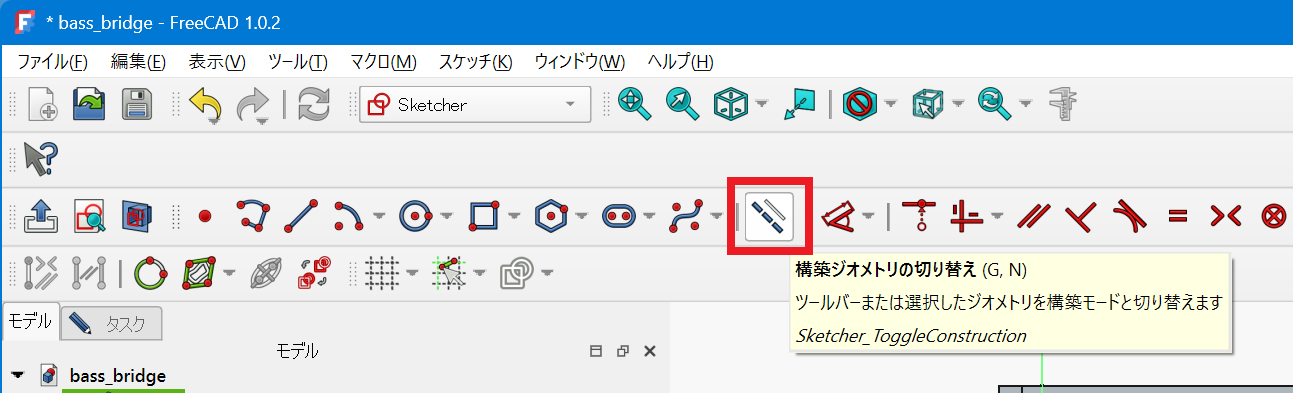
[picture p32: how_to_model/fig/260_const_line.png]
「構築ジオメトリの切り替え」ボタンで補助線の作成モード（構築モード）に切り替えられる


この状態で「直線を作成」ボタンをクリックし、続けてマウスカーソルをX軸上の適当な位置に動かします。ここでマウスカーソルに円弧のアイコンが表示されていることを確認してクリックすると、始点がX軸上に拘束された状態で直線作成を開始できます。

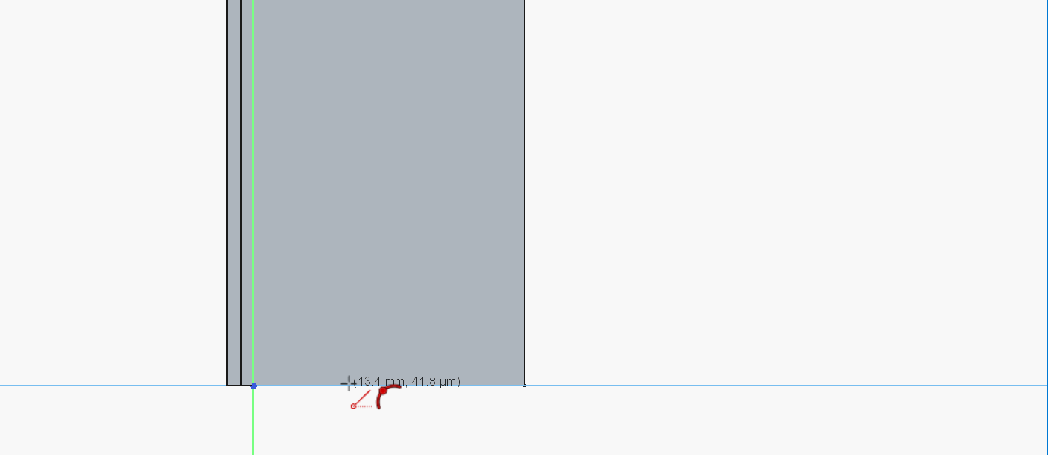
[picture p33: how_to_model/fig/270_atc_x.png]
X軸上にマウスを動かすとカーソルの横に円弧上のアイコンが表示され、ここでクリックするとX軸上に拘束された始点を作成できる


そのままマウスを真上に動かしてY軸と平行に線が描かれた状態にし、マウスカーソルに「｜」が表示された状態で適当な場所をクリックすると、始点からX軸に対して垂直（つまりY軸に対して平行）に拘束された直線を作成できます。

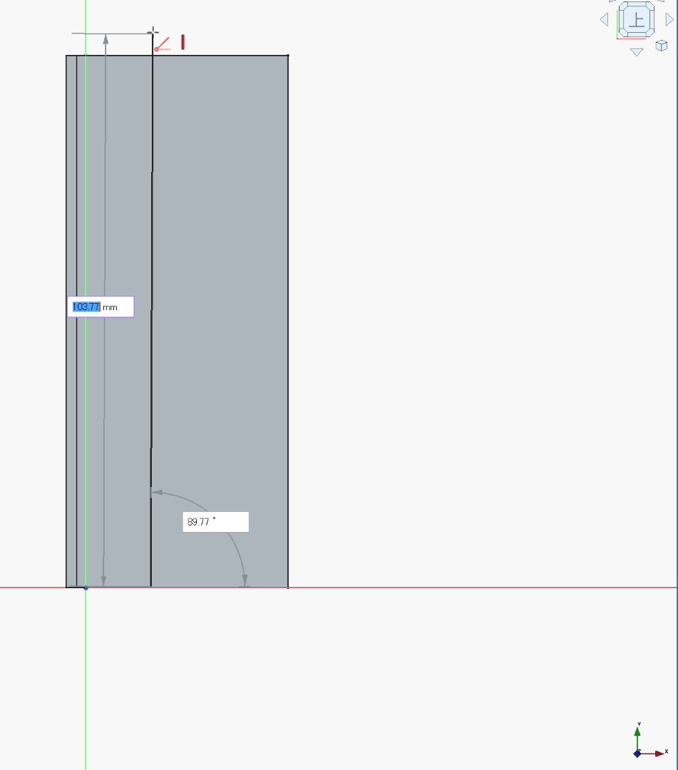
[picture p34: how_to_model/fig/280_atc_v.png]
カーソルの横に「｜」アイコンが表示された状態でクリックすると、垂直に拘束された直線を作成できる


続いてマウスの右ボタンをクリックして図形作成モードを一旦終了させたうえで、まずスケッチの原点をクリックし、次に先ほど作成した補助線をクリックしてからツールバーの「寸法」ボタンをクリックします。するとX軸から補助線までの寸法線が描かれるので、マウスを動かして寸法表示を適当な場所に移動させてからクリックし、寸法（今回は6mm）を入力して寸法線を確定させます。

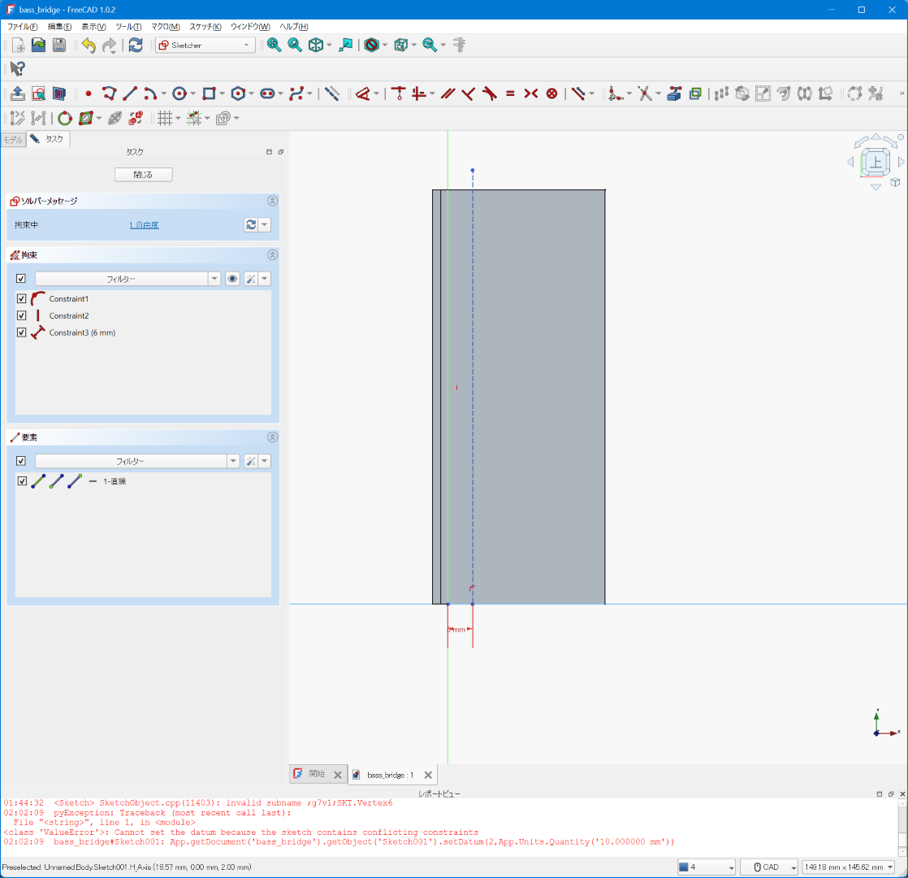
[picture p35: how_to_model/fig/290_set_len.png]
寸法線を追加して補助線のY軸からの距離を確定させる


この状態では、補助線の始点と角度は拘束されていますが、終点（つまり補助線の長さ）は拘束されていません。そのため、この補助線の長さは確定しておらず、終点をマウスでドラッグすることで長さを変えることができます。この状態では長さだけが自由に変更できるため、マウスタスクタブの「ソルバーメッセージ」には「1 自由度」と表示されます。なお、補助線については完全拘束にする必要はないので、このままにしておきます。

また、今回は穴の縦方向（Y軸方向）の位置は台座の中心を基準に指定したいので、同様にして横方向（X軸に対して平行）の補助線も作成して寸法を設定しておきます。

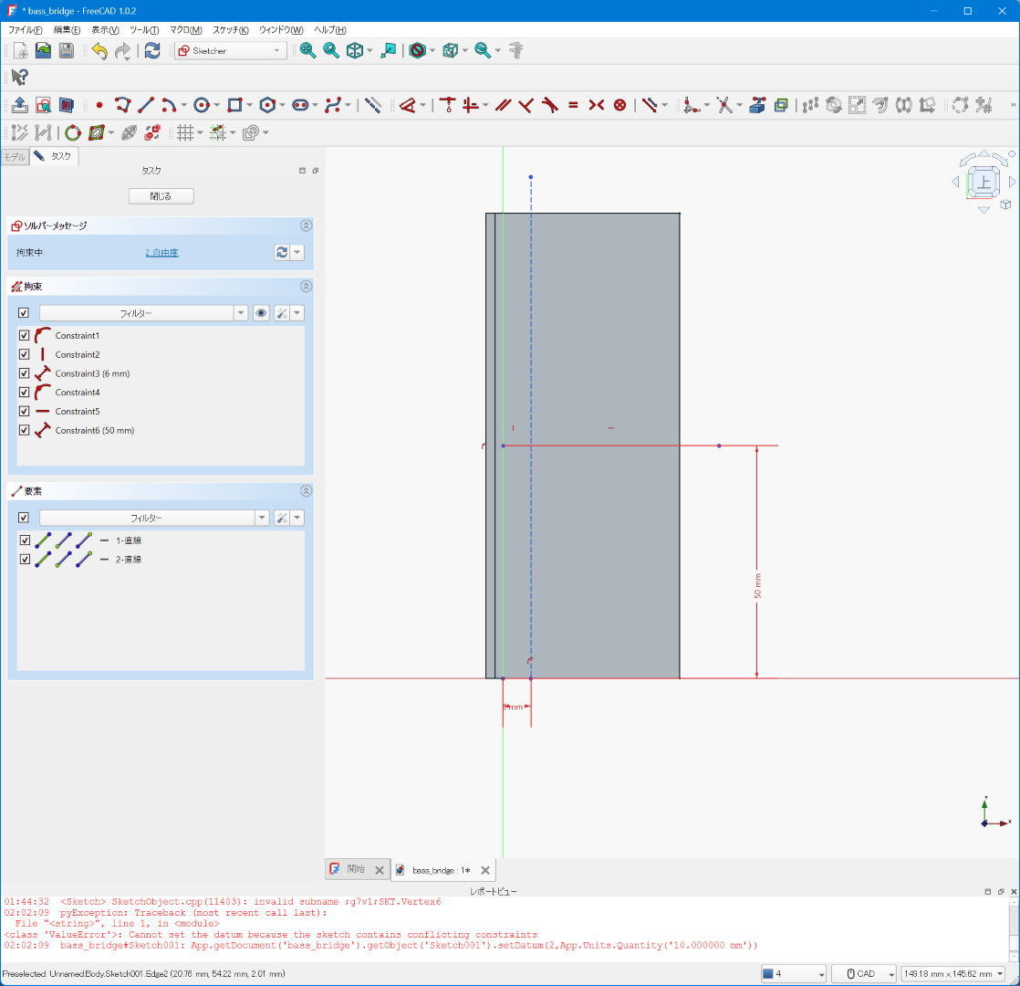
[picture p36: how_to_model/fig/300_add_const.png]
台座縦方向の中心、つまり端から50mmの位置に水平な補助線も追加する


続いてネジ穴を空ける場所に円を作成していきます。まず、ツールバーの「構築ジオメトリの切り替え」ボタンをクリックして白い実線表示に変更してからツールバーの「中心を指定して円を作成」ボタンをクリックします。

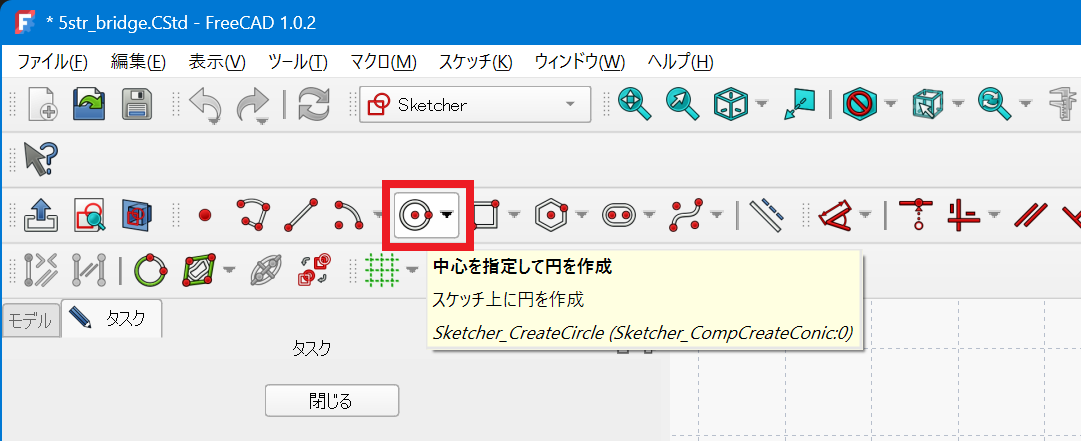
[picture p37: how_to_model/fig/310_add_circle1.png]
「中心を指定して円を作成」で円を作成する


次に、スケッチ上で先ほど作成した縦方向の（Y軸と平行の）補助線上の適当な場所をクリックして、中心が補助線上に拘束された円を作成します。このとき、カーソルの横に円弧のアイコン（拘束表示アイコン）が表示されていることを確認してからクリックします。

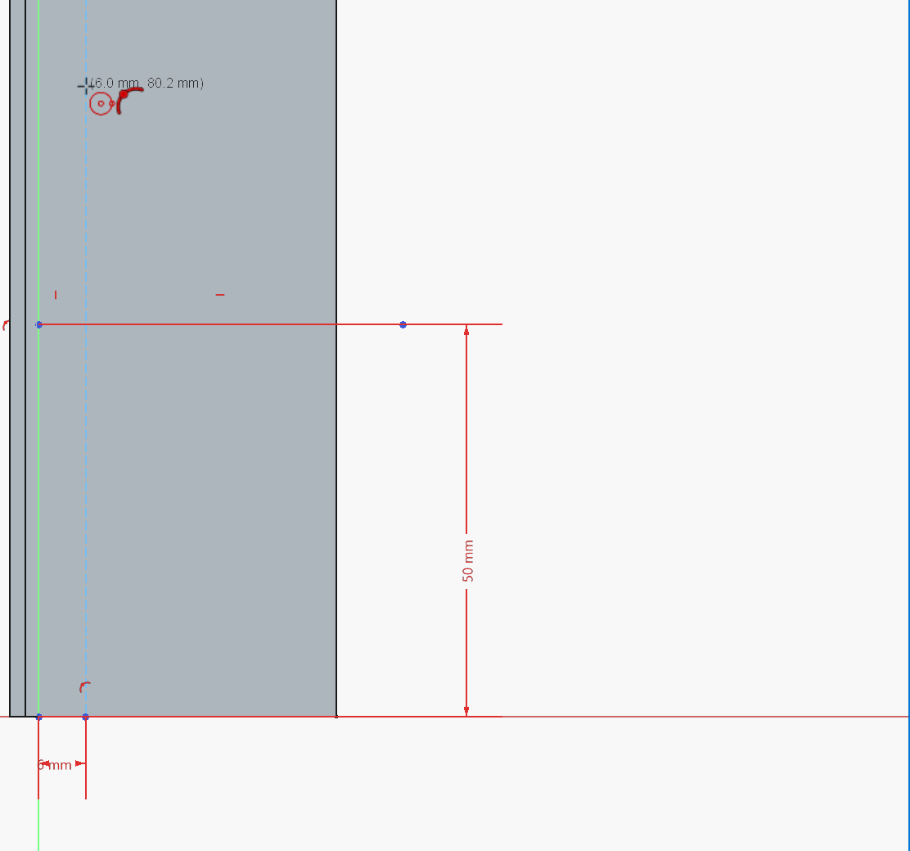
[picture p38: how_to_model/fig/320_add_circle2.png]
「中心を指定して円を作成」が選択された状態で補助線上をクリックすると中心が補助線上に拘束された円を作成できる


マウスを動かすと円の直径が変わるので、適当な直径で再度左クリックして円の中心と直径を確定させます。なお、キーボードで寸法を入力してEnterキーを押すことで、明示的に直径を指定した（直径が拘束された）円を描画することもできます。ただ、最初の台座を作成する際に長方形を描いたときと同様、この時点では位置とサイズは適当で構いません。

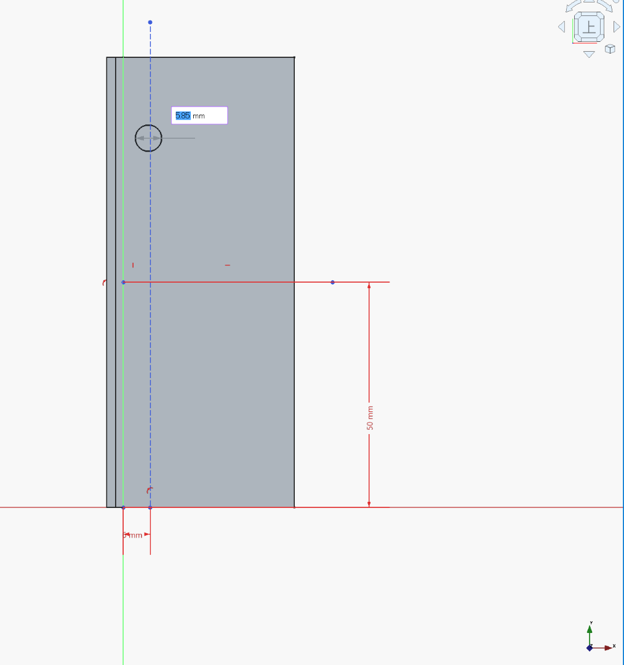
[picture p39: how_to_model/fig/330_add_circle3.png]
マウス操作で作成する円の直径を指定できる


同じ作業を繰り返して、6つの円を補助線上に作成します。なお、このときカーソル横に表示されるアイコンが「><」にならないように注意してください。アイコンが「><」の場合、中心が補助線上の特定の位置に拘束されてしまい、あとから位置（X軸からの距離）を変更できなくなってしまいます。

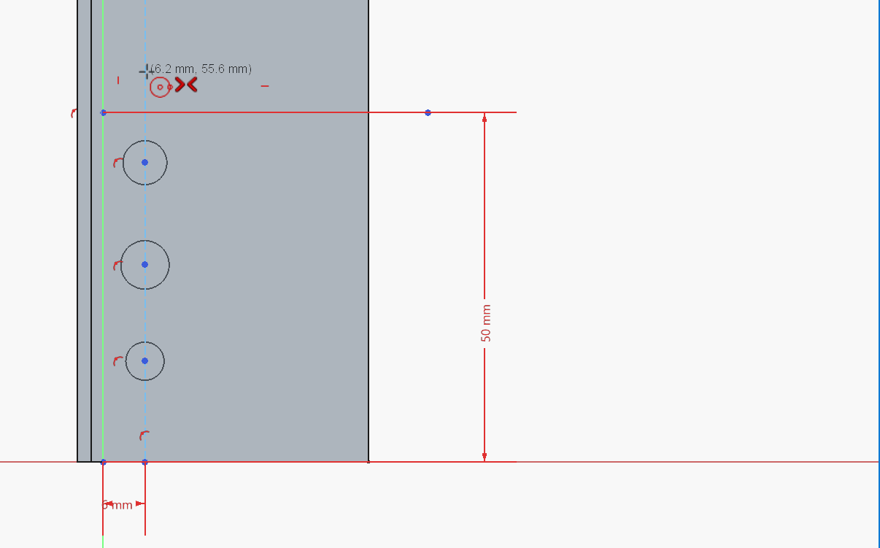
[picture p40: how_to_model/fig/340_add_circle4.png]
円の中心を指定する際、カーソル横に「><」アイコンが表示された状態でクリックすると円の中心の縦位置もその位置に拘束されてしまうので注意する


次に横方向（X軸と平行）の補助線を基準として円の寸法を記入していきます。まず何も選択していない状態で補助線をクリックし、続いて寸法を記入する円の中印をクリックして、寸法線と対象の円が選択された状態にします。このとき、タスクタブの「要素」で対象の要素をクリックして選択することでも同じ操作が可能です。

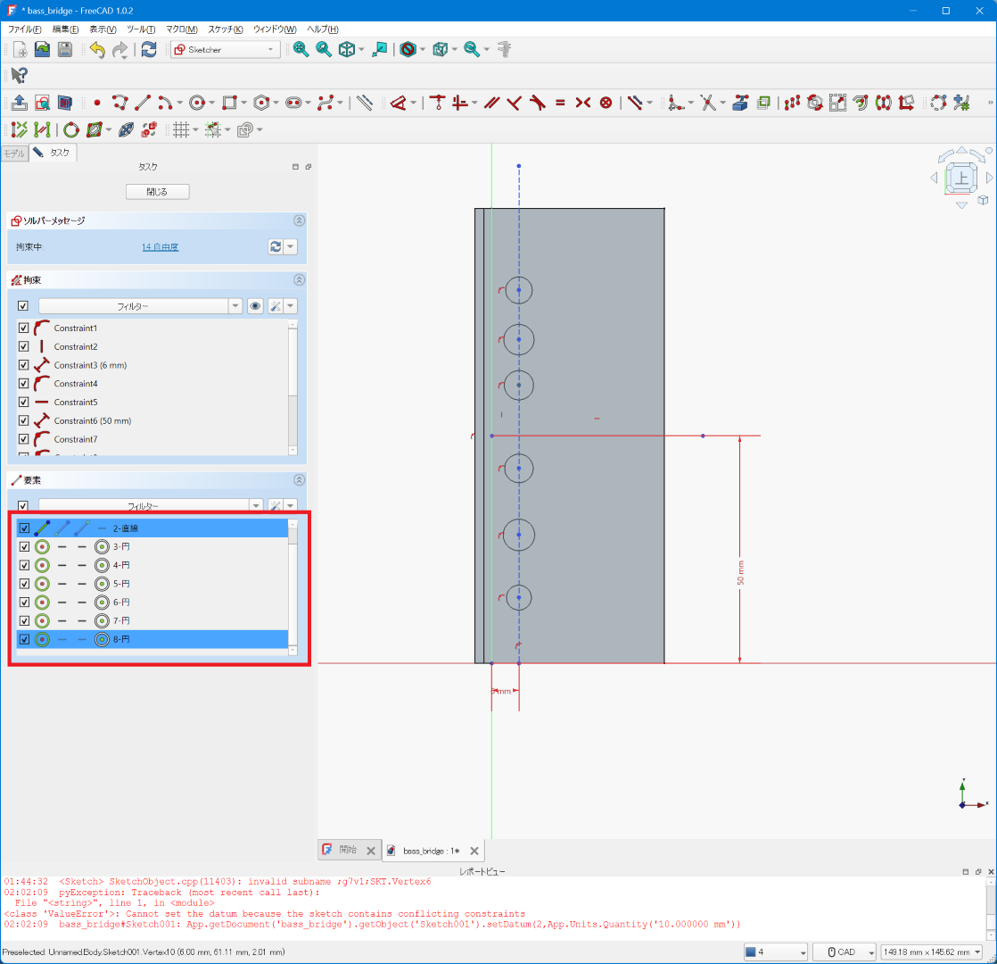
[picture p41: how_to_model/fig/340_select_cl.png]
補助線（直線）と円をクリックして選択する


この状態でツールバーの寸法ボタンをクリックすると、寸法線から円の中心までの間に寸法線が描かれます。ここで寸法を適当な場所に動かしてから左クリックで位置を決め、最後に長さ（今回は9.2mm）を入力して寸法線を確定させます。

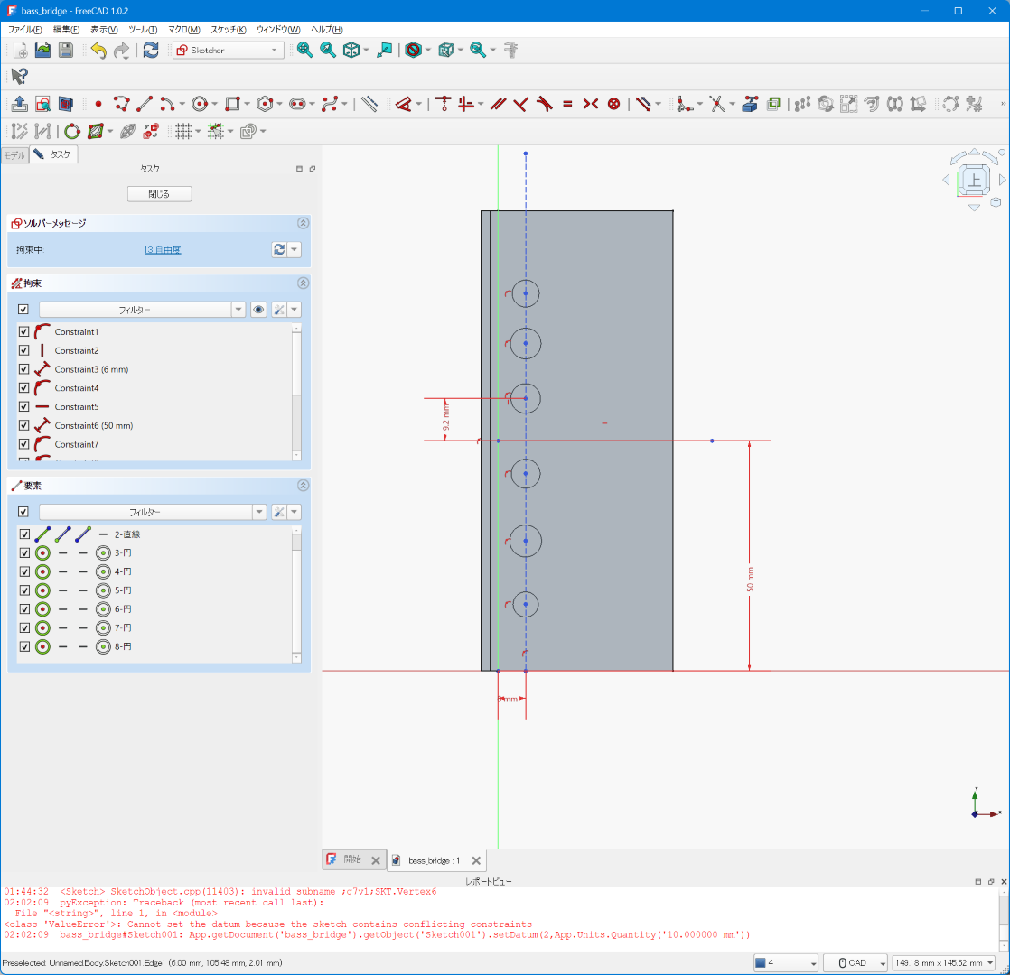
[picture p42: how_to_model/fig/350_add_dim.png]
補助線と円の中心の間に寸法線を作成する


また、1番上の円と2番目の円の中心を順にクリックし、寸法ボタンをクリックすると、それぞれの円の中心間に寸法線を作成できます。

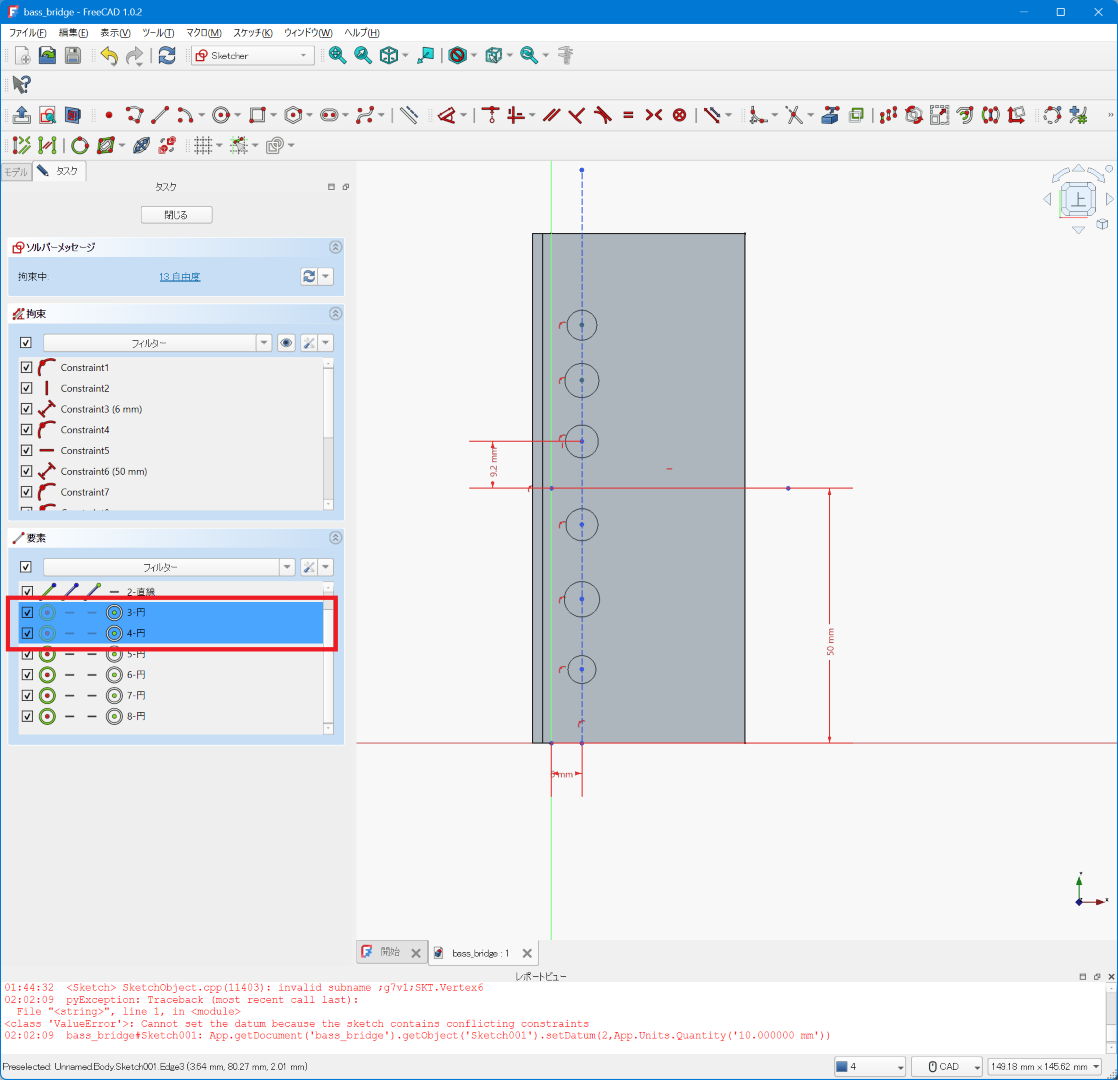
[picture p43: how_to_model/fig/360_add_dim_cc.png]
円を2つ選択して寸法ボタンをクリックすると、その中心間を結ぶ寸法線を作成できる


この作業を繰り返して、6つの円すべてに寸法線を記入します。

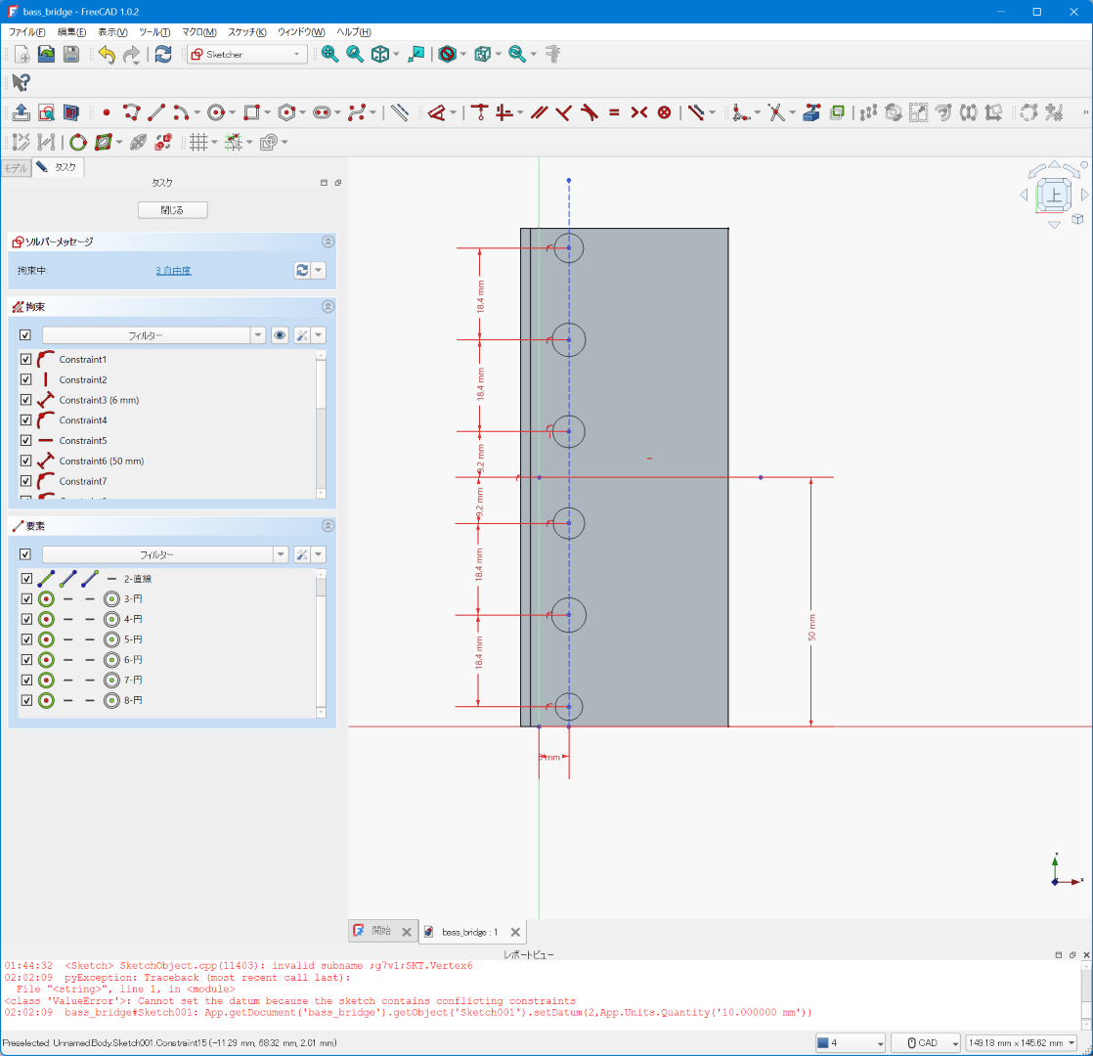
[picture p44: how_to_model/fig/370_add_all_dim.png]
6つの円の中心に対してすべて寸法線を記入する


さて、続いては穴の直径を指定するのですが、今回はネジ穴をPart Designワークベンチの「Hole」機能を使って作成します。この場合、Hole機能のほうで穴の直径を指定できるため、スケッチ上では穴の直径を指定する必要はありません。そのため、ここで一旦Escキーを押してPart Designワークベンチに戻り、「Sketch001」を選択した状態でツールバーの「Hole」ボタンをクリックします。

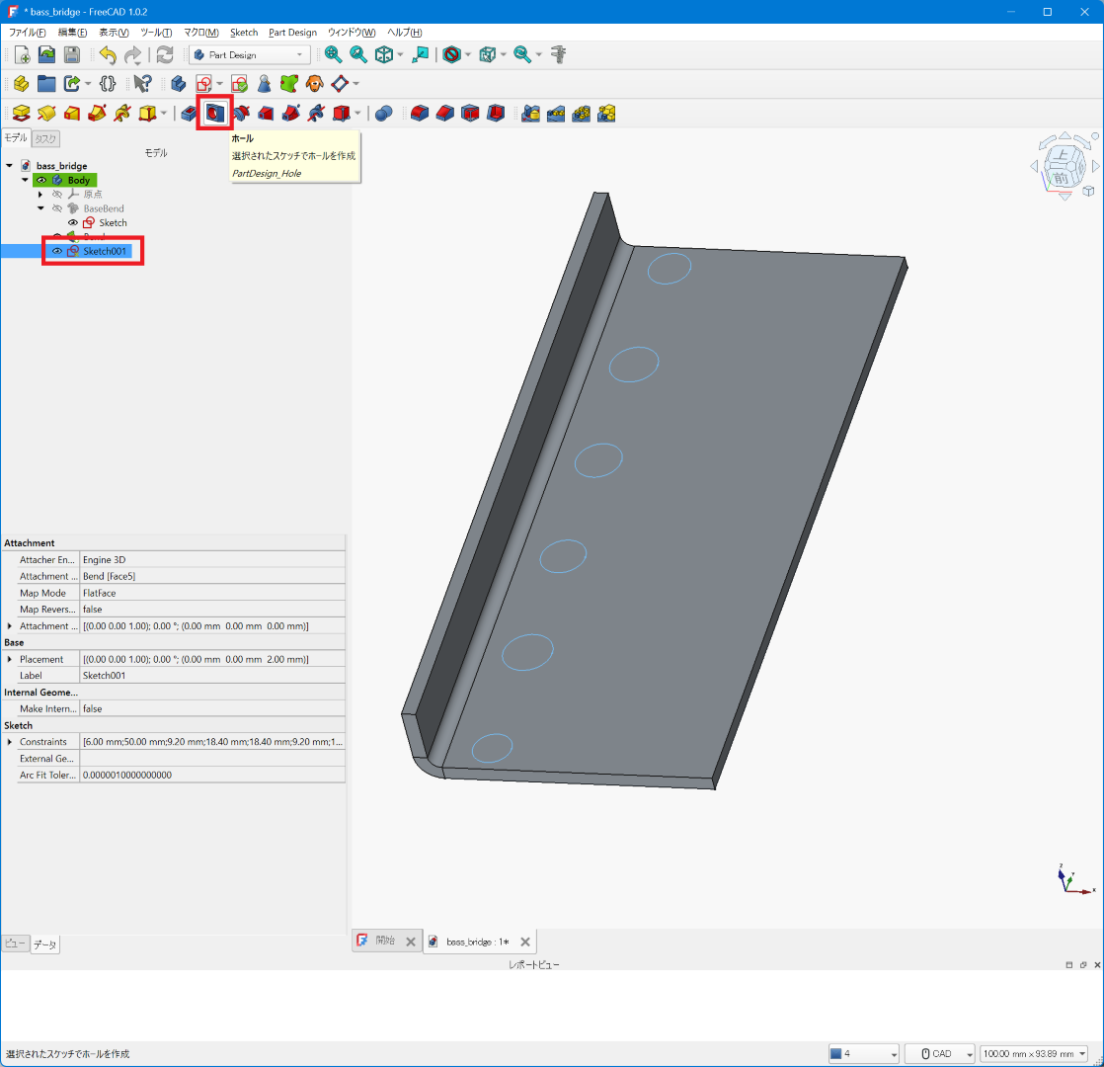
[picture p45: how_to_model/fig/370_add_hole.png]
Part Designワークベンチでスケッチを選択し「Hole」ボタンをクリックする


タスクタブで「ホールパラメータ」画面が表示されるので、ここで穴のサイズなどを指定します。今回は「直径」を4.3mm、「深さ」は「貫通」、「ホールカットのタイプ」は「皿穴」で以下「直径」を7mm、「深さ」は0mm、「皿穴の角度」は90°に設定しました。最後に「OK」をクリックすると皿穴が作成されます。

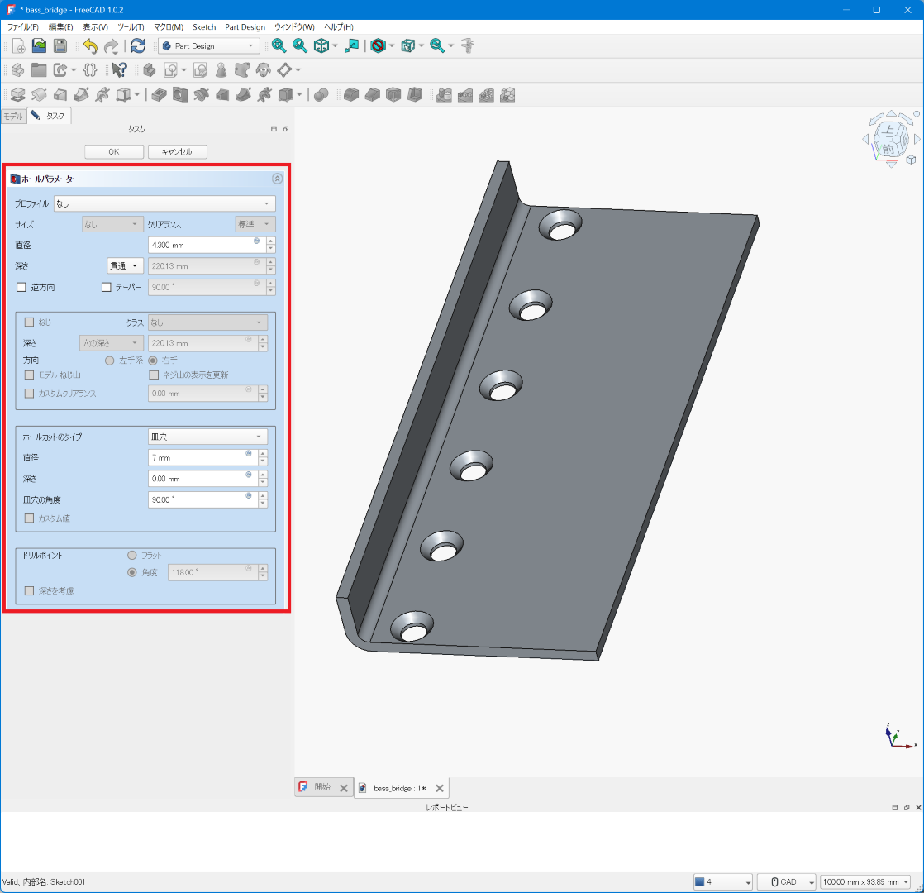
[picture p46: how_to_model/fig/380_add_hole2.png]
「ホールパラメータ」で穴の仕様を決める


Hole機能で穴を作成すると、同時に「モデル」タブのBody以下にこの穴に対応する「Hole」という項目が作成されます。この項目をダブルクリックすれば、再度タスクタブで穴の直径などを再度変更することが可能です。また、BaseBendと同様にこのHoleの下に先ほど作成したスケッチ（「Sketch001」）は残されており、このスケッチを編集することであとから穴の位置を変更できます。

Bodyの下に「Hole」項目が作成される

## 弦を通す穴を作成する

次は弦を通す穴を作成します。この穴は台座を90度曲げた部分、つまりBody以下の「Bend」部分に作成するので、この面にスケッチを作成します。まずPart Designワークベンチで対象とする面を選択してからタスクタブで「スケッチを作成」をクリックします。これで、「Sketch002」というスケッチが作成され、Sketcherワークベンチに切り替わります。

台座を90度曲げた部分の外側の面を選択してスケッチを作成する

弦を通す穴は円ではなく、上側の角のみを丸めた長方形として作成します。これらの長方形の高さはすべて同じです。そのため、高さを決めるための補助線を最初に作成します。まずSketchを開いた状態で、ツールバーの「構築ジオメトリの切り替え」ボタンが青い点線表示になっていることを確認します。もし白い実線表示になっている場合は、このボタンをクリックして青い点線に切り替えてから先ほどと同じ手順で補助線を作成します。穴の高さは5mmなのですが、後述するように四角形の中心を基準に位置決めを行うため、ここでは補助線の台座底面（つまりY軸）からの距離を2.5mmに設定します。

台座底面から2.5mmの位置に水平な補助線を作成する

次に、「構築ジオメトリの切り替え」ボタンをクリックして白い実線表示に切り替えてから、ツールバーの「四角形」ボタン横の「▼」をクリックし、ここで表示される「中心配置長方形」項目をクリックします。

ツールバーの「中心配置長方形」をクリックする

中心配置長方形では、長方形の中心と縦・横のサイズを決めることで位置とサイズを拘束できる長方形を作成できます。まず、この中心配置長方形が選択された状態で補助線上をクリックし、長方形の中心を補助線上に拘束して長方形の作成を開始します。このとき、カーソル横に円弧アイコンが表示された状態、つまり補助線上に拘束される状態になることを確認してからクリックしてください。

まず補助線上をクリックして長方形の中心を補助線上に拘束する

次にY軸（台座の底面）上の適当な場所をクリックし、下辺がY軸上に拘束された長方形を作成します。ここでもカーソル横に円弧アイコンが表示された状態になっていることを確認してからクリックします。これにより、長方形の中心が補助線、下の辺が台座部分の底面（つまりY軸）に拘束された長方形が作成されます。

続いてY軸上をクリックし、下辺がY軸上に拘束された長方形を作成する

続いて長方形の横の辺をクリックして選択してから寸法ボタンをクリックし、長方形の幅を記入します。これで長方形の幅も拘束されました。

寸法ボタンを使って長方形の幅を記入する

弦を通す穴は5つ必要なので、同様にしてあと4つ長方形を描いてそれぞれの幅を寸法線として記入します。

合計5つの長方形を作成して幅を記入する

次はそれぞれの穴の位置を記入します。弦を通す穴のうち1つは台座のちょうど中心部分、つまり台座の端から50mmの位置に配置されているので、四角形の中心と台座の端、つまりZ軸との間に寸法線を作成して位置を拘束します。まず原点をクリックし、続いて四角形の中心をクリックしてから寸法ボタンをクリックするとZ軸からの距離を記入できます。

長方形のうち1つの中心とZ軸との距離を記入する

また、穴と穴の間隔は19mmなので、それぞれの四角形の中心を結ぶ寸法線を作成してほかの穴の位置も拘束します。

穴の中心間の寸法を記入していく

最後に、穴の上部分のみ角を丸めます。まずツールバーの「フィレットを作成」ボタンをクリックし、次に丸めたい角を構成する辺2つを順にクリックする、もしくは丸めたい角の頂点をクリックします。

「フィレットを作成」で角を丸める

これで選択した角が丸まるので、次に丸まった部分の上側の部分の端（ドットが表示されている部分）と穴の縦の辺を順にクリックしてから寸法ボタンをクリックし、角丸の半径を決める寸法線を作成します。今回は半径を2mmに設定しています

フィレットに寸法線を追加する

これで角丸のサイズも拘束されます。同様にして、すべての長方形の上側の角を丸めていきます（ちなみに、寸法ボタンにはショートカットキーとして「D」キーが割り当てられているので、右クリックで選択解除→角丸の端点をクリック→穴の縦の辺をクリック→D→寸法の位置をクリックして決定→寸法入力、を繰り返すことで素早く作業できます）。

位置とサイズが完全拘束された穴が完成する

スケッチでの作業はこれで完成です。ソルバーメッセージには「1 自由度」となっていますが、穴はすべて緑色の線（完全拘束）で表示されているはずです。続いてタスクタブの「閉じる」ボタンをクリックしてPart Designワークベンチに戻り、モデルタブでSketch002を選択した状態で「ポケット」ボタンをクリックします。これによってスケッチに描画した図形で3Dモデルをくり抜くことができます。

「ポケット」でスケッチに描画した図形を切り抜くことができる

「ポケットパラメータ」では、「タイプ」を「寸法」に設定し、くり抜く深さを「長さ」で指定します。今回は10mmに設定しました。「方向/エッジ」は「スケッチ法線」、「スケッチ法線に沿った長さ」にチェックを入れ、テーパー角度は0度で「OK」をクリックします。
「ポケットパラメータ」でくり抜く深さなどを指定する

これで弦を通す穴がくり抜かれました。この穴は、モデルタブでは「Pocket」という項目名のアイテムに対応しています。

Bodyの下に「Pocket」が追加される

## サドル固定用ネジのネジ穴を空ける

次はサドルを固定するネジを挿入する穴を開けていきます。この穴も台座を90度曲げた部分、つまりBody以下の「Bend」部分に作成します。弦を通す穴と同じスケッチにネジ穴を描いていっても良いのですが、弦を通す穴は「ポケット」操作で開けたのに対し、ネジ穴は「ホール」操作で開けるほうが自由度が高いため、同じ面に別のスケッチを作成して描いていきます。

スケッチ作成の手順は弦を通す穴と基本的に同じで、Part Designワークベンチで面を選択してからタスクタブで「スケッチを作成」をクリックします。

再度側面にスケッチを追加する

これによって新たに「Sketch003」というスケッチが作成され、Sketcherワークベンチに切り替わります。

「Sketch003」というスケッチが作成される

これまでの作業と同様に、このスケッチ上で穴を開ける位置に円を描いていきます。作業の流れも今までと同じで、まず円の中心を決定するための補助線を作成します。円の中心は台座の底面から8.4mmに設定しているので、この高さの水平補助線と、台座の幅方向の中心に垂直の補助線を作成します。

まず補助線を作成する

続いて穴を5つ作成します。

穴を5つ作成する

最後に寸法を入れていきます。穴の中心は弦を通す穴の中心から水平方向に5mm離れた場所に設定しました。穴と穴の間隔は弦を通す穴の間隔と同じ19mmです。

寸法を記入する

スケッチで円の作成と寸法の記入が完了したら、タスクタブの「閉じる」をクリックしてPart Designワークベンチに戻り、Sketch003を選択した状態で「ホール」ボタンをクリックして穴を開けます。

「ホール」ボタンをクリックして穴を開ける

穴の直径は4mm、深さは「貫通」、「ホールカットのタイプ」は「なし」に設定しています。これでサドルを固定するためのネジ穴が完成しました。

「ホールパラメーター」で穴の仕様を設定する

## 面取りをする

これでブリッジの基本的な形状は完成しました。最後に、角の尖った部分を丸めていきます。Part Designワークベンチで丸めたい辺を選択し、「フィレット」ボタンをクリックします。

丸めたい辺を選択し、「フィレット」ボタンをクリックする

タスクタブの「フィレットパラメーター」で丸める半径を入力し、「OK」をクリックします。

「フィレットパラメーター」で丸める半径を指定する

この作業をすべての丸めたい辺に対して行います。今回は台座のネック側の2箇所を半径2mmで、弦を通す部分（台座から90度折り曲がった部分）の2箇所を半径5mmで丸めています。

同じ作業を繰り返して4つの角を丸める

以上でモデリングの作業は完了です。

## ファイルをエクスポートする

FreeCADで設計した3Dモデルを業者に発注する際には、通常は汎用のファイル形式にエクスポートしてそのファイルを渡します。まず、モデルタブでエクスポート対象（今回は「Body」）を選択します。

モデルタブでエクスポートする対象を指定する

続いて「ファイル」－「エクスポート」メニューを選択すると保存先を指定するダイアログが表示されます。

「ファイル」－「エクスポート」でエクスポートを行う

エクスポートする形式は「ファイルの種類」で選択できます。たとえばJLCCNCに発注する際には、「STEP with colors」形式（拡張子は.step）で保存します。

エクスポートする形式を指定して保存する
